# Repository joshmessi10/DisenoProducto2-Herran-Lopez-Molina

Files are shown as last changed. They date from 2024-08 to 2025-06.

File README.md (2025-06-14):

# 📦 Project Design: Smart Wallet

A multidisciplinary project focused on designing a Smart Wallet with enhanced security, tracking, and real-time data access, featuring custom PCB, mobile application, web integration, and mechanical design.

## 🧠 Features Overview
### 🔐 Security

- Unauthorized access protection
- Anti-loss alarm (Bluetooth disconnection)
- Fall detection
- Precise location recovery

### 📱 Functionality
- Bluetooth communication with Android app (BLE)

- Real-time statistics:
- Date and time of wallet openings
- Detection of abnormal movements
- Unauthorized access logs
- Last known location

### 🔧 Ergonomics and Durability

- Compact PCB design to fit in standard wallets
- BLE for low power consumption and long battery life

# 📁 Repository Structure
```plaintext
SmartWallet/
│
├── README.md                  <- General overview (this file)
│
├── hardware/
│   ├── README.md              <- Schematic, PCB layout (2D & 3D), test results
│   ├── schematic/             <- Altium files
│   ├── pcb/                   <- GERBER files, 2D/3D renders
│   └── testing/               <- Images/videos of pre-solder and post-solder testing
│
├── firmware/
│   ├── README.md              <- Microcontroller code overview
│   └── src/                   <- C/C++ source code
│
├── android_app/
│   ├── README.md              <- App features and Bluetooth integration
│   └── SmartWalletApp/        <- Full Android Studio project
│
├── web/
│   ├── README.md              <- Website functionality and usage
│   └── site/                  <- HTML/CSS/JS or framework files
│
├── database/
│   └── README.md              <- MongoDB Atlas structure and integration
│
└── casing_design/
    ├── README.md             
    └── 3d_models/             <- STL, OBJ, Fusion/Inventor files
```

## 🛠 Technologies Used

- **PCB Design:** Altium
- **Microcontroller:** nRF51822
- **Bluetooth:** BLE (Low Energy)
- **Mobile App:** Android (Java/Kotlin)
- **Database:** MongoDB Atlas
- **Web:** HTML/CSS/JS or framework (React/Vue/etc.)
- **3D Design:** Fusion 360

## 🚀 Getting Started

To explore each part of the project, navigate into the corresponding folder and refer to its README.md.

# 👥 Credits

Alejandro Buelvas García

Josh Sebastián López Murcia

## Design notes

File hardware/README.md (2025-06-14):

# PCB Design

Smart Wallet PCB Design using Altium Designer.

## Schematic

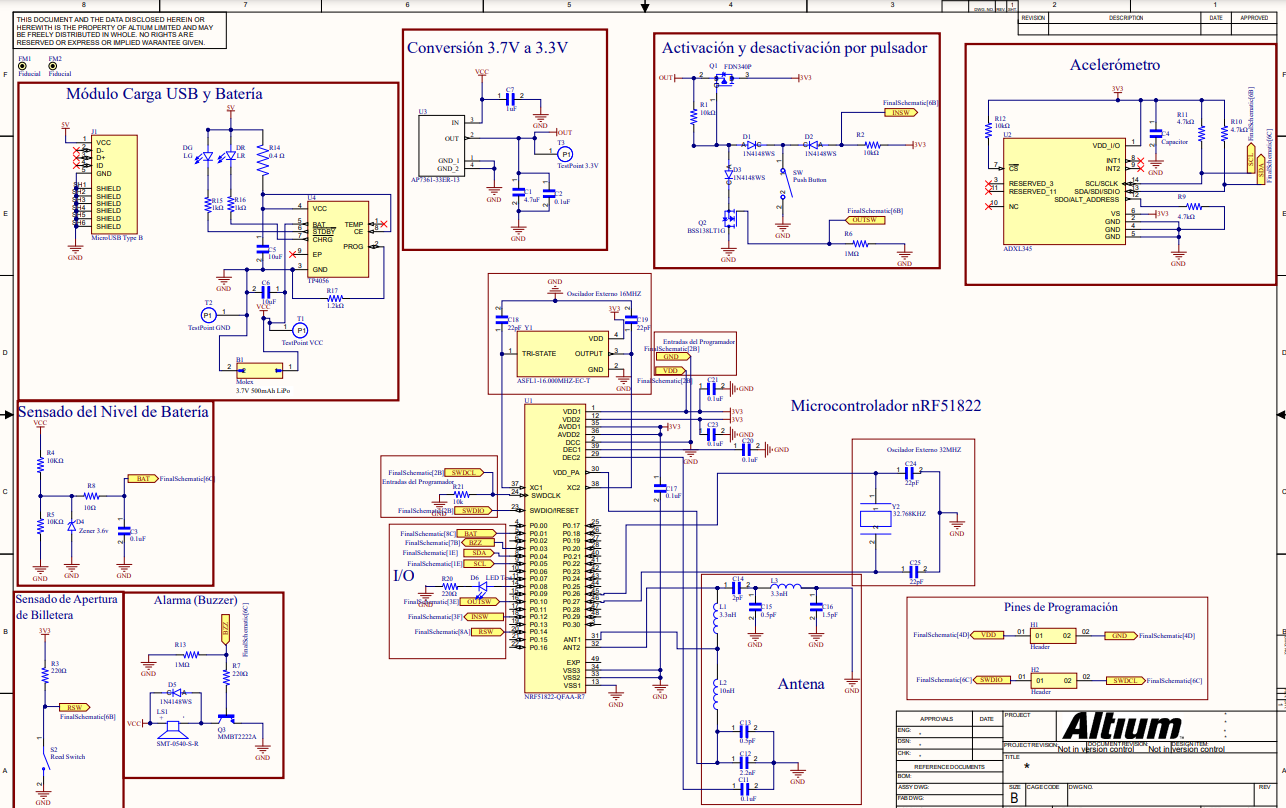
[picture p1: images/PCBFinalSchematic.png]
Schematic


## PCB Design Visualization

### 2D View

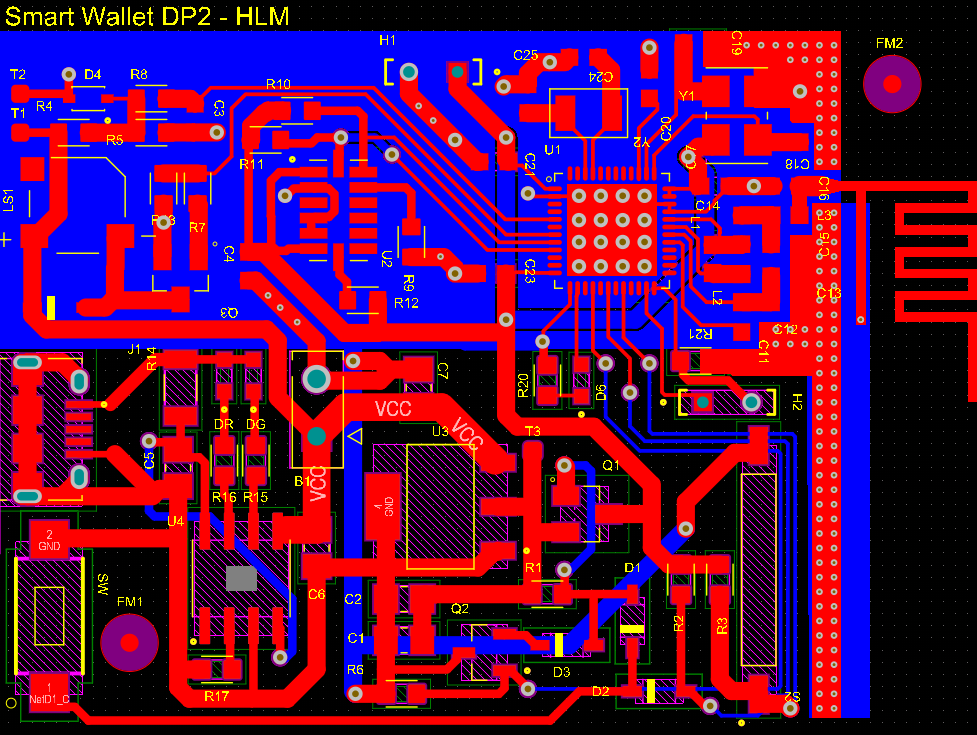
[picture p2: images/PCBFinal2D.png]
PCB 2D


### 3D View

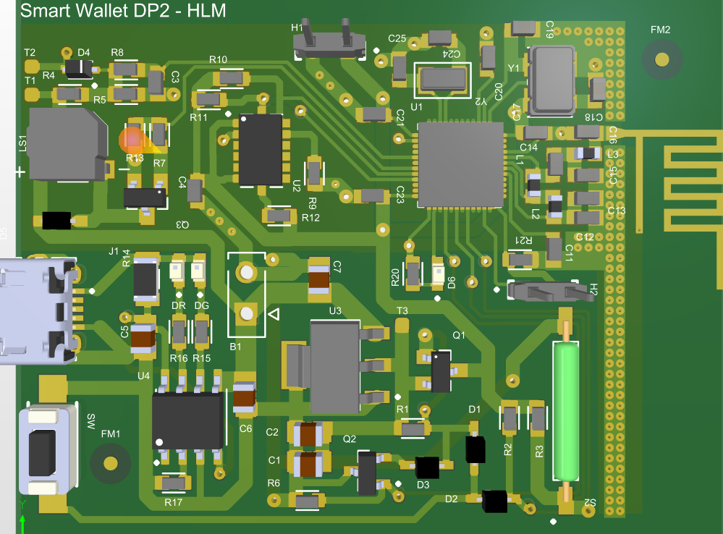
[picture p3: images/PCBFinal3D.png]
PCB 3D


[Download Link](https://drive.google.com/file/d/1_fBBA95fIbqjc8yl-Cb5X0gYM83vqySH/view?usp=sharing)

## PCB Assembly

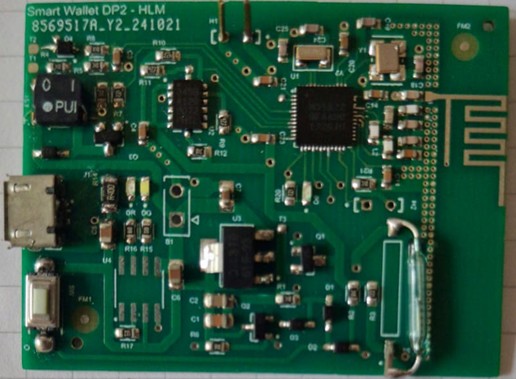
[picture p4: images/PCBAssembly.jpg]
PCB Assembly


Design Inspired from [Yunjia NRF51822](https://doc.riot-os.org/group__boards__yunjia-nrf51822.html#details)

[Integration of TP4056 Mini USB charge Module](https://www.electronicshub.org/tp4056-lithium-ion-battery-charger/)

2.4 GHz Monopole Antenna Design based on Antenna Design and RF Layout Guidelines by T Pattnayak

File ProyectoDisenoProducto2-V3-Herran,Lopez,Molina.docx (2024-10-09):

Proyecto Diseño de Producto 2

Estudiantes:

Juan Sebastián Herrán

Josh López

Sergio Molina

Asignatura:

Diseño de Producto 2

Universidad Sergio Arboleda

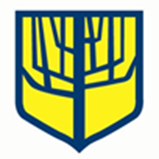
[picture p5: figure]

Escuela de Ciencias Exactas e Ingeniería

Ingeniería Electrónica

2024

Fase 1: Lluvia de Ideas

Producto | Ingeniería de Producto | | | Análisis de Mercado | | Restricciones
| ¿Se puede desarrollar? ¿Cómo? | ¿Es viable desarrollarlo? | | ¿A quién le interesa? | ¿Por qué sería llamativo? ¿Es una necesidad, una oportunidad o una solución? | A) Conectividad a la nube B) Batería C) Activación sin contactos mecánicos
| | Beneficios | Desventajas
Billetera Inteligente Ingeniería de Producto Análisis de Mercado Cumple Restricciones | Sí: Bloqueo RFID Conexión Wi-Fi /BLE GPS Alarma de Distancia Acelerómetro | Seguridad: Protección contra pérdidas y robos. Funcionalidad: Integración con otras tecnologías y dispositivos. Comodidad: Organización y pagos sin contacto | Complejidad (Integración de diferentes componentes en espacio reducido) Costos Bajo consumo de batería | Viajeros Frecuentes Estudiantes Profesionales Early Adopters | Es llamativo por las mejoras en seguridad y las nuevas funcionalidades que puede ofrecer. En Colombia casi no hay productos en el mercado. Representa una solución frente a robos en pro de la protección de los datos personales. | A) Sí B) Sí C) Sí
Chip Detector para ropa Ingeniería de Producto Análisis de Mercado Cumple Restricciones | Sí: Tecnología RFID (Chips y Lector) Conectividad Wi-Fi Pantalla Base de Datos | Inventario Preciso y Gestión eficiente Rastreo del Uso de cada Prenda Ahorro de Tiempo de selección de atuendos Recomendaciones personalizadas | Miniaturización y durabilidad de los chips Adaptación en la Ropa y Diseño a prueba de daños Software de Gestión para almacenamiento de datos en la nube y escalabilidad | Personas que buscan optimizar el uso de ropa, recibir sugerencias y reducir el tiempo de selección de ropa Personas que quieren ahorrar tiempo y esfuerzo comprando ropa Tiendas y fabricantes de ropa | Es llamativo porque brinda eficiencia, personalización e innovación implementando pequeños chips en la ropa. En varias tiendas de ropa de Colombia se utiliza esta tecnología. Representa una solución para la gestión del inventario y el tiempo que demora seleccionar un atuendo cada día. | A) Sí B) Sí C) Sí
Sistema de seguridad para maletas Ingeniería de Producto Análisis de Mercado Cumple Restricciones | No: Sensores magnéticos/Contacto Bocina Tecnología Bluetooth/Wifi | Seguridad contra robos y pérdidas Monitoreo de la maleta | Duración y Consumo Batería Colocación y Activación del Sistema Complejidad para el diseño e implementación del Sistema a prueba de cualquier tipo de robo Ej. Rotura de la maleta | Personas que buscan proteger sus pertenencias y/o llevan objetos valiosos | No es llamativo frente a un candado. Existen múltiples alternativas en el mercado. Representa una solución para los continuos robos de las pertenencias dentro de las maletas | A) Sí B) Sí C) Sí
Sistema de alarma para cocinas Ingeniería de Producto Análisis de Mercado Cumple Restricciones | Sí: Sensores de Gas/Humo/ Calor Mecanismo de cerrado de válvula Alarma sonora/visual Notificación Remota: Conectividad Wi-Fi | Mayor seguridad Tranquilidad frente a la no atención de la cocina o a encontrarse fuera del hogar Automatización del cierre de la válvula de gas Integración con otras tecnologías Detección temprana de fugas de gas y/o incendios Visualización de datos | Duración y Consumo Batería Sensado Preciso y Falsas Alarmas Mantenimiento Ubicación y Activación del Sistema Costo | Personas ocupadas/olvidadizas Personas que buscan proteger su hogar de fugas de gas y/o incendios | Es llamativo al presentar una solución, planteada como de bajo costo, que permite detectar con antelación y actuar de manera automática. Representa una solución para las fugas de gas y/o incendios, así como para el cierre automático de la válvula de gas. | A) Sí B) En Duda C) Sí
Sistema detector de consumo (ropa, comida) - . Ingeniería de Producto Análisis de Mercado No Cumple Restricciones | Sí: Conectividad a Internet Cámaras de alta resolución Visión Artificial | Control de inventario de ropa, personalizaciones etc. Control del inventario de comida, evita la perdida de algún producto y reduce los gastos del usuario en algunos casos Control del inventario de comida, control de salud y control de gastos en comida | Complejidad: Requiere mucho tiempo de desarrollo. Requiere diseñar y probar un sistema avanzado de detección, a prueba de fallas, en muy poco tiempo. Altos Costos | Personas que tengan bastante ropa/comida Personas que sean descuidadas o desorganizadas, empresas con un alto nivel de inventario Personas que quieran o requieran un control más sano del consumo de la comida actual | Es llamativo al presentar una utilidad para el control del inventario, sin importar cuál sea. Representa una oportunidad para controlar el uso de la ropa, el consumo de comida, el control de gastos, etc. | A) Sí B) No C) Sí
Sistema detector de disponibilidad de restaurantes Ingeniería de Producto Análisis de Mercado Cumple Restricciones | Sí: Conectividad Wi-Fi GPS (Datos de Ubicación) Aplicación Móvil Base de Datos | Menor tiempo de búsqueda de restaurantes disponibles Mayor Ingreso a Restaurantes | Simplicidad Beneficios principalmente brindados desde la nube Detección de presencia (mesa disponible/no disponible) | Personas que quieren localizar restaurantes libres en menor tiempo Restaurantes que quieren atraer clientes de manera efectiva | Es llamativo al presentar una solución innovadora y de bajo costo que se puede implementar en cualquier mesa y en cualquier restaurante, para atraer más clientela. Representa una solución para localizar los restaurantes con disponibilidad de manera rápida y efectiva. | A) Sí B) Sí C) En Duda
Espejo inteligente - . Ingeniería de Producto Análisis de Mercado No Cumple Restricciones | No: Pantalla Sensores Cámara: Vision Artificial IoT | Sencillez Estética Ahorro de Tiempo para arreglarse | Alta Complejidad Altos Costos por unidad Alto Precio | Todas las personas | Es llamativo al presentar una herramienta tecnológica para mejorar el estilo y la estética de las personas. Representa una oportunidad para ahorrarse tiempo arreglándose y recibir los mejores consejos. | A) Sí B) No C) Sí
Módulo GPS portable - . Ingeniería de Producto Análisis de Mercado No Cumple Restricciones | No: GPS Conectividad Wi-Fi | Seguridad Tranquilidad, Movilización Monitoreo de la Ubicación | Costo de producción vs. Precio Atractivo Muy Pocas funcionalidades Simplicidad Complejidad en la Conexión a Internet y a la nube Bajo consumo de batería | Niños | Es llamativo al presentar una herramienta tecnológica, planteada de bajo costo, para el monitoreo de la ubicación. Representa la atención a la necesidad del monitoreo constante de la ubicación de los niños. | A) Sí B) Sí C) No
Alacena Inteligente - . Ingeniería de Producto Análisis de Mercado No Cumple Restricciones | No: Sensores de Peso Actuadores para ubicar objetos Revisión de alimentos faltantes o cerca de vencerse | Reducción del desperdicio de alimentos Mejora de la organización Alimentación saludable Ahorro de tiempo | Complejidad Altos Costos vs. Proceso Manual Tamaño Tiempo de Desarrollo, Iteraciones y Pruebas Potencia Necesaria desde Alimentación del Sistema Requiere espacios fijos para los alimentos | Personas que quieren ahorrar tiempo en la cocina, y con gran capacidad adquisitiva. | Es llamativo al presentar una herramienta tecnológica para la organización automática de la alacena. Su alto precio no sería llamativo. Representa una oportunidad para ahorrarse tiempo en el proceso. | A) Sí B) No C) No
Estuche Gafas Inteligente - . Ingeniería de Producto Análisis de Mercado Cumple Restricciones | Sí: Tecnología Bluetooth Pantalla | Comodidad: Carga inalámbrica y sencilla. Funcionalidades Adicionales a un estuche convencional Integración: Se integra con otras tecnologías, como asistentes virtuales. | Pocas Funcionalidades Limitada Recolección de Estadísticas Complejidad para funcionalidades específicas | Personas que portan gafas que quieren un producto innovador Early-adopters | Es llamativo al presentar una innovación frente al estuche convencional. Representa una oportunidad para integrar la tecnología al estuche de gafas y conectarlo al IoT. | A) Sí B) Sí C) Sí

Análisis Criterios Iniciales:

DP2-T0-Herran,Lopez,Molina.xlsx (https://universidadsergioarboleda-my.sharepoint.com/:x:/g/personal/josh_lopez01_usa_edu_co/EcgmHX4n6xtBkdCwMJmsrzgBQwG7WUzlyEpB4xwgIX4yPQ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)

Fase 2: Filtrado de Ideas

Producto | ¿Es amplio el mercado objetivo? | ¿El mercado objetivo realmente se beneficiará del producto? | ¿Es técnicamente viable fabricar este producto? | ¿Generaría beneficios este producto en el tiempo?
Billetera Inteligente | Por supuesto. Todos los estudiantes y profesionales manejan una billetera para cuidar su dinero y documentos. | Por supuesto. El producto les garantizaría mayor seguridad en cuanto a la posibilidad de extraviar o ser víctimas de robo de su billetera. | Por supuesto. Se necesitarían componentes de bajo consumo y tamaño reducido. | Entre más popular se vuelva el producto, se generará una mayor rentabilidad, planteando un bajo costo y múltiples funcionalidades novedosas.
Chip Detector para ropa | No lo suficiente, pues solo las personas interesadas en la innovación del producto estarían dispuestas a comprarlo. Además, muchas tiendas de ropa ya implementan esta tecnología. | Por supuesto. A los usuarios les permitiría conocer la frecuencia de uso de su ropa y reducir tiempo al obtener recomendaciones de combinaciones de prendas para utilizar cada día. A las tiendas les permitiría un óptimo manejo del stock. | Por supuesto. Implica un menor costo en términos de tecnología RFID, pero todas las funcionalidades vendrían ligadas al software. | Depende de lo popular que se vuelva y lo útil que pueda llegar hacer, por lo que, al no poder producirse en masa, no generaría mucha rentabilidad.
Sistema de alarma para cocinas | Por supuesto. Todos los hogares podrían adquirir e implementar un sistema de bajo costo para sus cocinas. | Por supuesto. Desde el cerrado automático de la válvula de gas hasta el sistema de alarma y el monitoreo de datos, el producto presenta múltiples beneficios. | Por supuesto. Sin embargo, necesitaría una serie de pruebas para determinar los mejores sensores de bajo costo, y reducir el tamaño mientras siga cumpliendo sus requerimientos funcionales. | Depende tanto de su popularidad como principalmente de su precio, por lo que puede no generar mucha rentabilidad.
Sistema detector de nivel de llenado de restaurantes | Por supuesto. Todos los restaurantes pueden implementar el sensor que permite detectar si la mesa está ocupada, y conectar los datos a una aplicación móvil. Además, muchos empleados que buscan restaurante con disponibilidad para almorzar se verían beneficiados con la aplicación. | Por supuesto. En términos de eficiencia para encontrar restaurante disponible, y los propios restaurantes para obtener mayor clientela. | Por supuesto. No obstante, la mayor dificultad radica en detectar con certeza si una mesa se encuentra ocupada (sensor de presencia). | Depende de la cantidad de restaurantes que implementen dicha tecnología, por lo que en tanto se vuelva popular, puede generar rentabilidad. Sin embargo, no muchos restaurantes tenderían a apostar por el producto, pues el mayor beneficio recae en el cliente.

Ideas Seleccionadas:

1. Billetera Inteligente
2. Sistema de Alarma para cocinas

Fase 3: Desarrollo del concepto y prueba

3.1. Encuestas

1. Sistema de alarma para cocinas

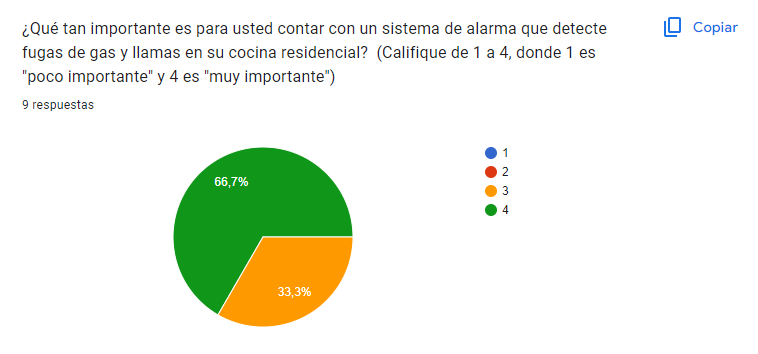
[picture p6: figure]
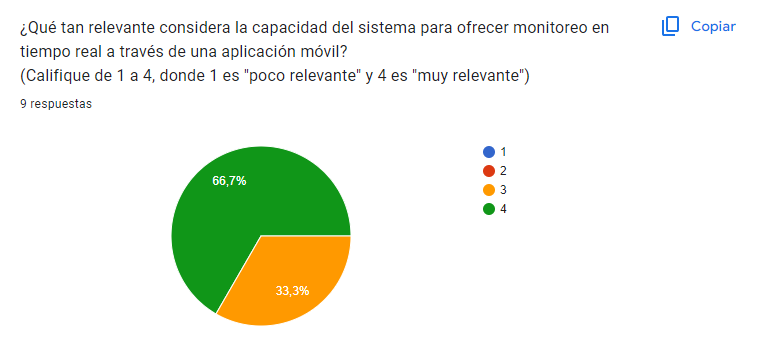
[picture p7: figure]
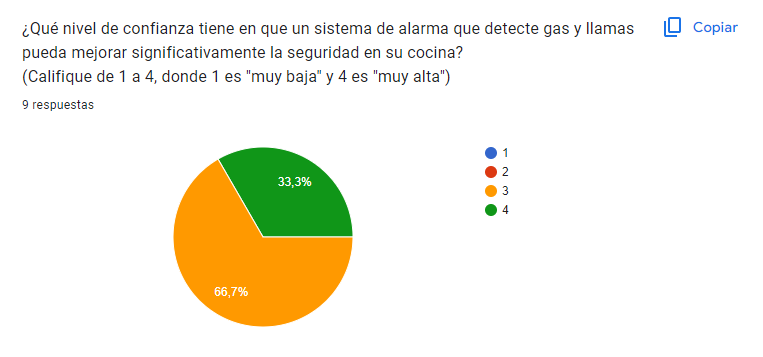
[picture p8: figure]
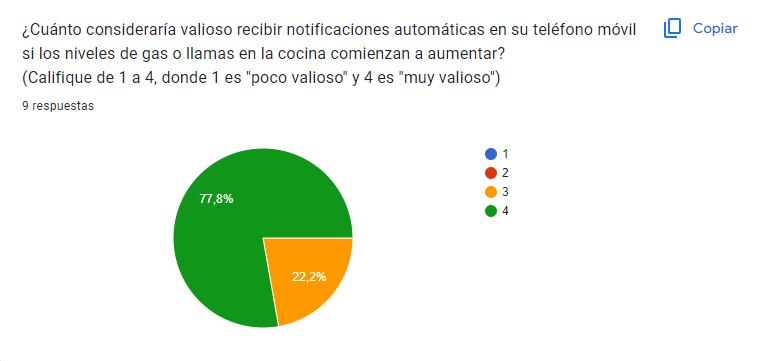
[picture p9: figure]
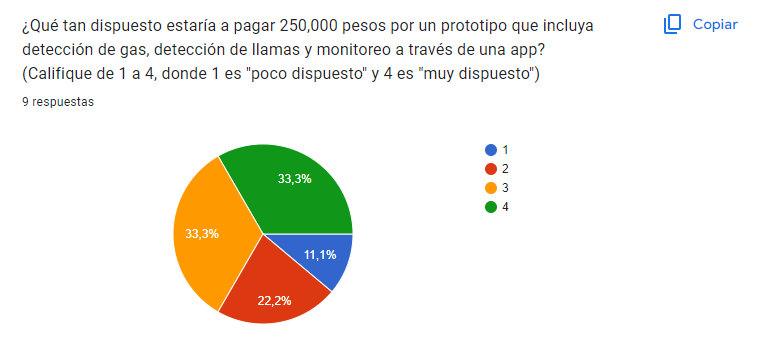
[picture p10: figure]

Link de la encuesta: https://forms.gle/PwD4ogpmBEbutgUVA

2. Billetera inteligente

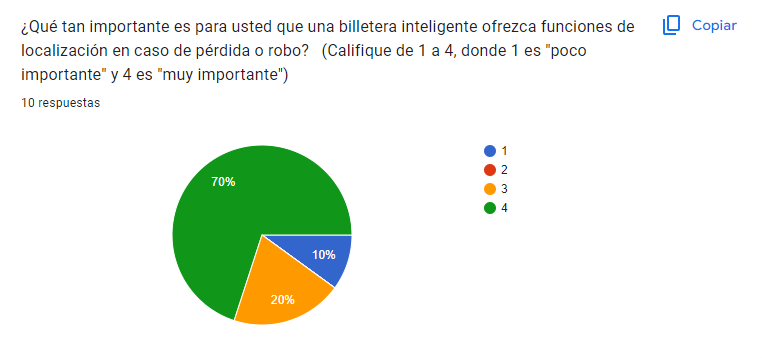
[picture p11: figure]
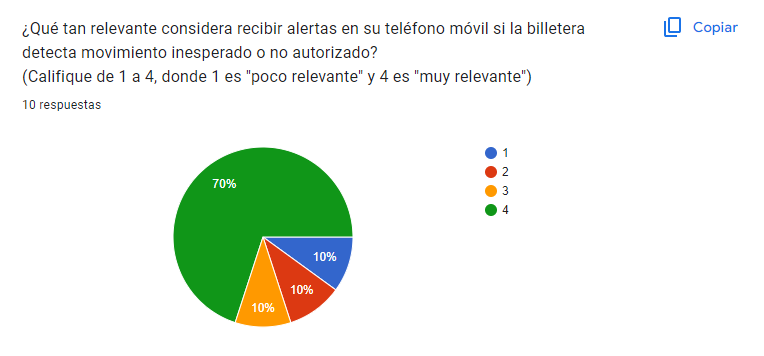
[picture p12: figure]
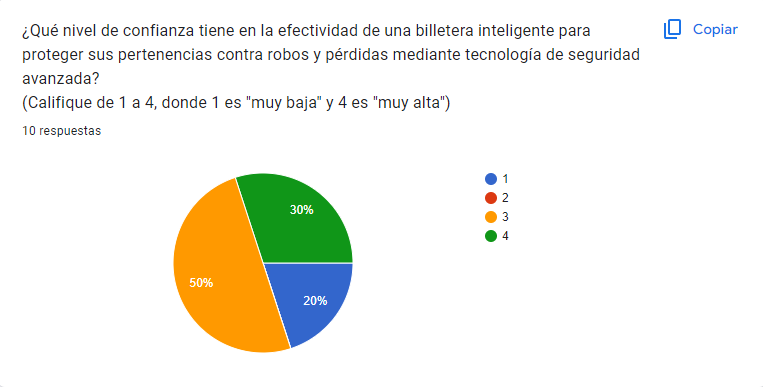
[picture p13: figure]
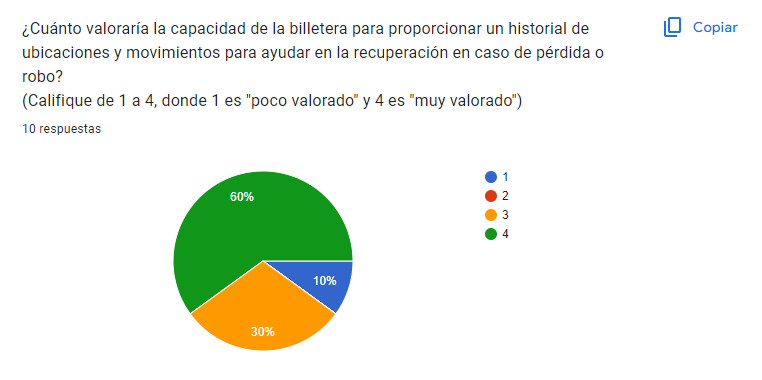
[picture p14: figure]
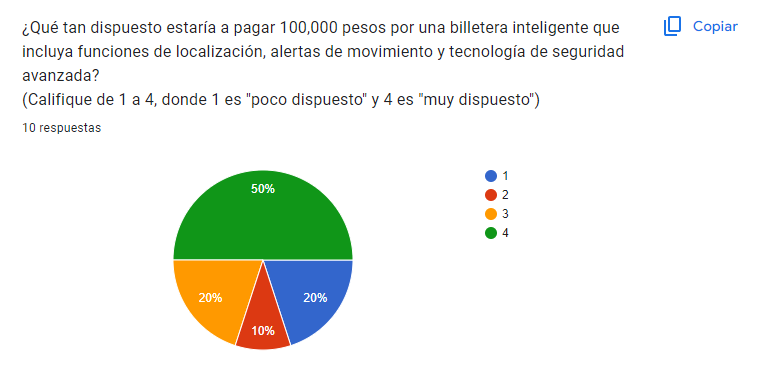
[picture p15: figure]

Link de la encuesta: https://forms.gle/VZ8JmRUWkLo8zy4EA

Fase 3: Desarrollo del concepto y prueba

A) Billetera Inteligente

1. Detalles de Marketing e Ingeniería

Marketing:

Identificación del Público Objetivo:

Jóvenes adultos y profesionales: Buscan tecnología innovadora, practicidad y seguridad.

Viajeros frecuentes: Valorarán las funciones de rastreo y seguridad en sus desplazamientos.

Aficionados a la tecnología: Adoptan rápidamente nuevos gadgets y buscan productos con características avanzadas.

Estrategia de Comunicación:

Redes sociales: Crear contenido atractivo y visualmente impactante para plataformas como Instagram, TikTok y Facebook.

Influencer marketing: Colaborar con influencers tecnológicos y de estilo de vida para llegar a un público más amplio.

Publicidad: Tiendas de tecnología y convenios con marcas de billeteras.

Canales de Venta:

Tiendas online: Vender a través de la propia tienda online y Marketplaces como Amazon, Mercado Libre, etc.

Tiendas físicas: Colaborar con tiendas de electrónica y accesorios de moda.

Distribuidores especializados: Llegar a un público más nicho a través de tiendas especializadas en tecnología.

Mensajes Clave:

Seguridad: Protección frente a robos y pérdidas.

Innovación: Tecnología de vanguardia y funcionalidades novedosas.

Conveniencia: Pagos sin contacto, organización de tarjetas y acceso a información importante.

Estilo: Diseño elegante y moderno que complementa cualquier atuendo.

1. Mercado Objetivo
- Jóvenes adultos y profesionales: Buscan tecnología innovadora, practicidad y seguridad.
- Viajeros frecuentes: Valorarán las funciones de rastreo y seguridad en sus desplazamientos.
- Aficionados a la tecnología: Adoptan rápidamente nuevos gadgets y buscan productos con características avanzadas.
2. Beneficios
- Seguridad:
  - Protección contra acceso no autorizado
  - Alarma por Alejamiento
  - Detección de caídas accidentales
  - Localización precisa en caso de pérdida
- Funcionalidad:
  - Integración con aplicación móvil
  - Comunicación via Bluetooth
  - Estadísticas en tiempo real: (Fecha y hora de apertura, movimientos anormales, registro de acceso no autorizado, registro de ubicación/última ubicación disponible)
- Ergonomía:
  - Tamaño reducido para integración en cualquier billetera
- Durabilidad:
  - BLE (Bluetooth Low Energy): Larga duración de la batería

Fase 3: Desarrollo del concepto y prueba

3.2. Requerimientos

A) Billetera Inteligente

Requerimientos Funcionales

3. Detección de apertura para protección con Intrusiones (Determinar si el acceso es o no autorizado) (Estados On/Off)
4. Notificación de Alejamiento de la billetera (Desconexión por Distancia mayor a 10 metros)
5. Autonomía Energética – 12 horas de batería
6. Detección de caída (-1g=-9.81m/s²)
7. Comunicación vía Bluetooth Low Energy (Protocolo BLE – 2.4GHz)
8. Almacenamiento de datos históricos (500 kilobytes)
9. Registro de actividades (apertura, movimientos sospechosos o no sospechosos) (12 horas de registro)
10. Visualización de datos históricos en tiempo real (1 min de retraso)
11. Alerta sonora (Estados On/Off)
12. Señalización visual apertura o cierre – Leds (Estados On/Off)
13. Activación desde aplicación móvil (Estados On/Off)
14. Notificación del estado de batería – Leds (Rojo-Verde)
15. Registro de movimientos bruscos (Intervalo entre ±2g y ±4g =±19.62g - ±39.24 g)
16. Función de autoapagado para ahorro de energía (1 min sin conexión al celular)
17. Botón de encendido/apagado (Estados On/Off)
18. Botón de desbloqueo manual (Estados On/Off)
19. Temporizador de apertura de la billetera (1 min)
20. Señal sonora para localizar tu billetera (Estados On/Off)
21. Señalización batería cargada – Leds (Estados On/Off)

Requerimientos No Funcionales

1. Tamaño Reducido (6x3x0.16cm) (En Revisión)
2. Latencia de comunicación aceptable (10 ms – Protocolo BLE)
3. Bajo consumo de energía (Ej. 0.3 W en alto consumo) (En revisión)
4. Costo asequible ($60000) (En Revisión)
5. Seguridad de la información – Restricción contra intrusiones (Protocolo X)

(Conexión con cifrado BLE)

(Protocolo TLS/SSL para la aplicación móvil)

6. Copias de seguridad automáticas

(Disponibles en la aplicación para las últimas 48 horas)

7. Durabilidad y resistencia

(Materiales por definir)

8. Interfaz de usuario intuitiva

Paso 1: Registro en la aplicación móvil

Paso 2: Conexión de la billetera inteligente

Paso 3: Visualización de datos

9. Peso reducido (Por Definir)

3.3. Diagrama de Bloques Nivel 1

Billetera Inteligente

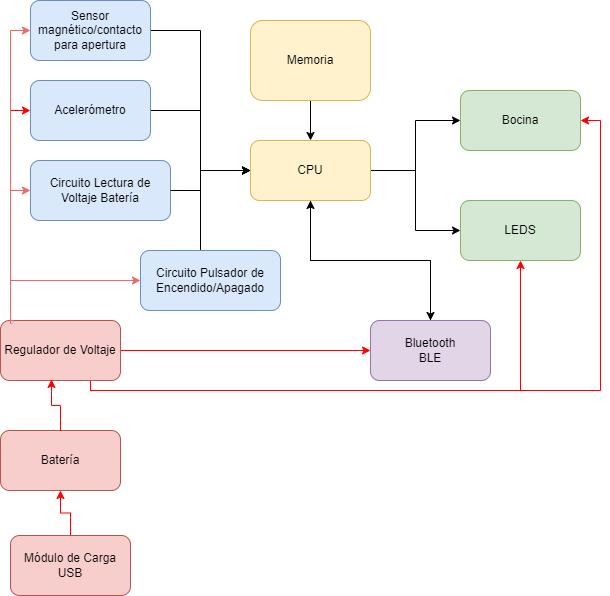
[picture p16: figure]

3.3.1. Búsqueda de Posibles Componentes

Microcontroladores

Componente | Precio | Voltaje | Corriente | Ventajas | Desventajas
ESP32 WROOM 32 | 20000-40000 COP | 2.7V-3.6V | Corriente típica de operación: 80mA | Integración de Wi-Fi y Bluetooth en un solo chip. Amplio soporte de GPIOs y periféricos. Muy popular y ampliamente soportado por la comunidad. | Mayor consumo de energía comparado con otros microcontroladores sin Wi-Fi/Bluetooth. Tamaño relativamente grande para aplicaciones ultracompactas.
Nordic nRF52840 QAAF | $10 USD | 1.7V-5.5V | Corriente típica de operación: Bluetooth 3.83-16.40 mA CPU: 2.8 – 5.2 mA | Muy bajo consumo de energía, ideal para aplicaciones alimentadas por batería. Excelente rendimiento en comunicaciones Bluetooth Low Energy (BLE). Alta integración de periféricos, incluyendo soporte para USB. | Menos potente en procesamiento que el ESP32. Más difícil de conseguir.
ESP32-S3 | 20000-40000 COP | 3-3.6V | 80-240mA | Mayor potencia de procesamiento, memoria y conectividad. | Mayor consumo de energía.
Nordic nRF51822 | $10 USD | 3.3V-5V | Corriente típica de operación: Bluetooth: 1.6mA-13mA Internal Radio Current Consumption: 7.8uA | Muy bajo consumo de energía, ideal para aplicaciones alimentadas por batería. Excelente rendimiento en comunicaciones Bluetooth Low Energy (BLE). | Menos potente en procesamiento que el ESP32. Difícil de conseguir. Menor cantidad de pines GPIO que en nRF52840.

ESP32 WROOM 32 : https://www.mouser.com/datasheet/2/891/esp-wroom-32_datasheet_en-1223836.pdf

Nordic nRF52840-DONGLE: https://infocenter.nordicsemi.com/pdf/nRF52840_PS_v1.1.pdf

ESP32-S3 : https://www.espressif.com/sites/default/files/documentation/esp32-s3_datasheet_en.pdf

Nordic nRF51822-DONGLE: nRF51x22 PS.book (nordicsemi.com) (https://infocenter.nordicsemi.com/pdf/nRF51822_PS_v3.1.pdf)

Acelerómetro

Componente | Precio | Voltaje | Corriente | Ventajas | Desventajas
MPU-6050 | 10000-15000 COP | 2.375V-3.46V | Corriente Operacional del: Acelerómetro: 500uA Giroscopio: 3.6mA | Integra acelerómetro y giroscopio, lo que permite la detección de movimiento en 6 ejes. Compatible con I2C, lo que facilita la integración con otros microcontroladores. Amplia comunidad de soporte y ejemplos de código disponibles. | Consumo de energía relativamente alto para aplicaciones alimentadas por batería. Sin características de bajo ruido o alta precisión en comparación con otros sensores.
ADXL345 | 7000-12000 COP | 2V-3.6V | 30uA – 150 uA (2.5V) | Bajo consumo de energía, ideal para aplicaciones alimentadas por batería. Amplio rango de ±2g, ±4g, ±8g, ±16g, configurable según la aplicación. Comunicación por I2C y SPI, facilitando la integración. | No es el más preciso en comparación con otros acelerómetros más avanzados. Tecnología más antigua, aunque sigue siendo ampliamente utilizada.

MPU6050 : https://www.alldatasheet.es/datasheet-pdf/download/517744/ETC1/MPU-6050.html

ADXL345: https://www.analog.com/media/en/technical-documentation/data-sheets/adxl345.pdf

LEDs

* Dependiendo del microcontrolador, la tarjeta puede tener LED, por lo que al elegir la tarjeta Nordic, no se incluye.

Componente | Precio | Voltaje | Corriente | Ventajas | Desventajas
Leds SMD 0805 | 300 COP | 2.7v-3.7v | 25 mA | Tamaño compacto, ideal para aplicaciones donde el espacio es limitado. Disponible en una variedad de colores. Bajo costo y ampliamente disponible. | Brillo limitado en comparación con LEDs más grandes. Requiere una cuidadosa soldadura debido a su pequeño tamaño.
Leds SMD 5050 | 400 COP | 2V-3.6V | 60-75 mA | Alto brillo, adecuado para iluminación y efectos visuales. Capaz de emitir varios colores (RGB) en un solo paquete. Relativamente fácil de soldar debido a su tamaño. | Consumo de energía más alto debido a los múltiples chips. Ocupa más espacio en la PCB.
Leds SMD 3528 | 300 COP | 1.7V-2.4V | 50 mA | Tamaño intermedio, adecuado para aplicaciones de señalización y decoración. Disponible en varios colores, incluyendo opciones de alto brillo. Más eficiente que los LEDs 5050 en términos de consumo de energía por chip | Menos brillante que los LEDs 5050. Menor gama de colores comparado con LEDs RGB.

Led SMD 0805: https://www.mouser.com/datasheet/2/143/17-21-BHC-AP1Q2-3T_datasheet-51933.pdf

Led SMD 5050: https://www.iled.com/class/INNOVAEditor/assets/YeniDatasheets/4050-4055-4057.pdf

Led SMD 3528: https://www.sigmaelectronica.net/wp-content/uploads/2018/08/LED-3528BLANCO.pdf

Alimentación

Componente | Precio | Voltaje | Corriente | Ventajas | Desventajas
Batería de litio-polímero (LiPo) | 25000-30000 COP | 3.7v | 500 mAh | Alta densidad de energía, lo que permite una mayor capacidad en un tamaño pequeño. Forma flexible, disponible en diferentes formas y tamaños, ideal para aplicaciones compactas. Peso ligero, adecuado para dispositivos portátiles. | Requiere un manejo cuidadoso para evitar sobrecargas o sobre-descargas, que pueden causar daños. Vida útil limitada en comparación con otras baterías recargables. Puede ser más cara que otras opciones de baterías.

Batería Li-Po: https://www.zamux.co/bateria-recargable-litio-37v-500ma

Módulo de Carga

Componente | Precio | Voltaje | Corriente | Ventajas | Desventajas
TP4056 y puerto Mini USB 1050170002 | 4000 COP | Input supply voltage: 4.25 – 6.5V | Input supply current: 35uA – 2 mA | Muy económico y ampliamente disponible. Configurable para diferentes corrientes de carga mediante la modificación de una resistencia. Fácil de integrar en proyectos DIY debido a su tamaño compacto. | Sin protección integrada por defecto (aunque hay versiones con protección). La corriente de carga puede ser limitada para baterías de mayor capacidad. Requiere soldadura si se necesita ajustar la corriente de carga.
Módulo de carga MCP73831 | 18000 COP | Input supply voltage: 3.75 – 6V | Input supply current: 510uA – 1.5 mA | Bajo consumo en reposo, ideal para aplicaciones de bajo consumo de energía. Muy eficiente en la gestión de la carga, prolongando la vida útil de la batería. Pequeño y fácil de integrar en PCB personalizadas. | Corriente de carga más baja (hasta 500 mA), lo que puede ser una limitación para baterías más grandes. Puede requerir componentes externos adicionales para ajustar el circuito.

TP4056: https://radioremont.com/wa-data/public/shop/products/32/33/3332/attachments/TP4056.pdf

MCP73831: https://www.alldatasheet.es/datasheet-pdf/download/305677/MICROCHIP/MCP73831.html

Circuito de Activación por Pulsador

Pulsador

Componente | Precio | Voltaje | Corriente | Ventajas | Desventajas
SW 4P NO | 400 COP | <42 V | <50mA | Tamaño pequeño, bajo costo. | Su tamaño puede dificultar la experiencia de usuario.

SW 4 Pines: https://cdn.soselectronic.com/productdata/f4/94/44a0b902/0862-8101.pdf

Mosfet Tipo N

Componente | Precio | Voltaje | Corriente | Ventajas | Desventajas
2N7002 | 600 COP | VGS (th): 1V to 2.5V | I DSS: 1 to 500 uA | Tamaño pequeño, bajo costo. | Difícil de soldar.

2N7002: https://www.diodes.com/assets/Datasheets/ds11303.pdf

Mosfet Tipo P

Componente | Precio | Voltaje | Corriente | Ventajas | Desventajas
FDN340P | 300 COP | VGS (th): -0.4V to -1.5V | I DSS: 1 to 10 uA | Tamaño pequeño, bajo costo. | Difícil de soldar

FDN340P: https://www.onsemi.com/pdf/datasheet/fdn340p-d.pdf

Resistencias:

Componente | Precio | Voltaje | Corriente
RES 1206 | 500 COP | Max 3.3V | Varía según el valor de la resistencia
RES 0603 | 500 COP | Max 3.3V | Varía según el valor de la resistencia
RES 0804 | 500 COP | Max 3.3V | Varía según el valor de la resistencia

Diodos

Componente | Precio | Voltaje | Corriente | Ventajas | Desventajas
1N4004 SMD | 200 COP | 0.7V | Average Forward Rectifier Current: 100mA | Tamaño pequeño, bajo consumo de energía, bajo costo

1N4007: https://www.alldatasheet.es/datasheet-pdf/download/209682/FCI/1N4007.html

Sensor de Apertura: Detección de Billetera Abierta/Cerrada

Componente | Precio | Voltaje | Corriente | Ventajas | Desventajas
Reed Switch ORD213 | 1200 COP | < 24 V | <100mA | Tamaño pequeño, bajo costo. | Requiere un imán/campo magnético al otro extremo para su activación/desactivación.

ORD213: https://standexelectronics.com/wp-content/uploads/OKI_Reed_Switch_ORD213.pdf

Regulador de Voltaje 3.3V

ME6217-3.3V | $0.075 USD | 3.4-6.5V Dropout Voltage: 100mV | Max Current Output: 800mA | Baja Caída de Voltaje Amplio rango de voltaje de operación | Reducción en la corriente de salida Difícil de conseguir
MIC502-3.3V | 600 COP | 3.4-6.5V Dropout Voltage: 150mV | Max Current Output : 500 mA Quiescent Current: 5uA | Fácil de conseguir Baja caída de voltaje Rango de Voltaje de Operación Óptimo | Voltaje de caída más alto dependiendo de la corriente de entrada Corriente de salida más baja
AP7361-33ER-13 | 1,547 COP | 2.2V – 6V. | 70 µA típica. | Capacidad de corriente de salida de hasta 1 amperio, es pequeño, adecuado para un montaje superficial. | Si se requiere de una potencia alta no es el regulador más adecuado, se consigue pero no es tan común solo pocas tiendas lo venden.

ME6217C33: MICRONE(Nanjing Micro One Elec) ME6217C33M5G Datasheet (lcsc.com) (https://www.lcsc.com/datasheet/lcsc_datasheet_1912111437_MICRONE-Nanjing-Micro-One-Elec-ME6217C33M5G_C427602.pdf)

MIC5205-3.3: https://www.vistronica.com/index.php?controller=attachment&id_attachment=574

Capacitores y Condensadores

Condensador Cerámico e Inductancia SMD | | 600 COP | | | Bajo costo Tamaño Reducido | Entre menor tamaño, más difícil para soldar

Diodo Zener

Zener SMD 3.6V | 200 COP | 3.6V | 5mA | Bajo costo Tamaño Reducido | Difícil para soldar

Zener 3.6V: Diodo Zener BZT52C3V6S W4 3.6V 200mW SMD SOD-323 (vistronica.com) (https://www.vistronica.com/componentes-activos/diodos/diodo-zener-bzt52c3v6s-w4-3-6v-200mw-smd-sod-323-detail.html)

Bocina

Bocina piezoeléctrica SMD: CMT-2020 | $2 USD | 2.5V-4.5V | 120mA | Tamaño pequeño, consumo de voltaje apropiado, bajo costo | No tiene un volumen muy alto, el sonido puede no ser de tan alta calidad Consumo de corriente considerable Difícil de conseguir
Bocina SMT-0540-S-R | 1250 COP | 3-12V | 30mA | Menor consumo de corriente Más fácil de conseguir | Tamaño más grande Volumen variable

SMT-0540-S-R: https://co.mouser.com/ProductDetail/PUI-Audio/SMT-0540-S-R?qs=e16JbV5WBEu5VaDVzQP23Q%3D%3D

3.4.2 Diagrama de Bloques Nivel 2

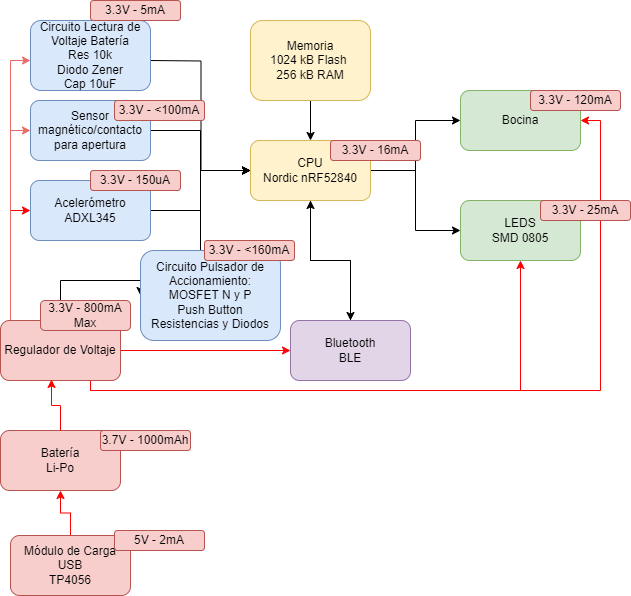
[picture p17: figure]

Fase 4: Diseño de Esquemático

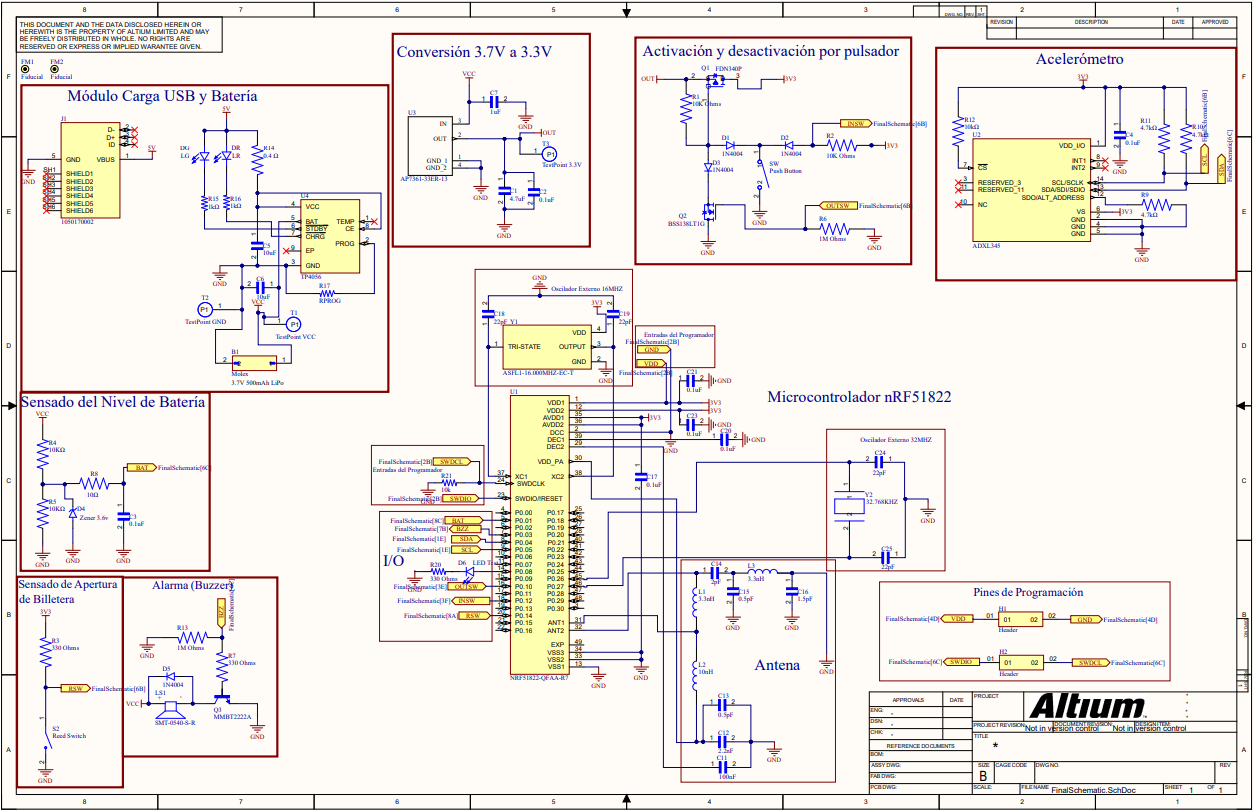
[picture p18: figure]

Fase 5: Diseño de PCB

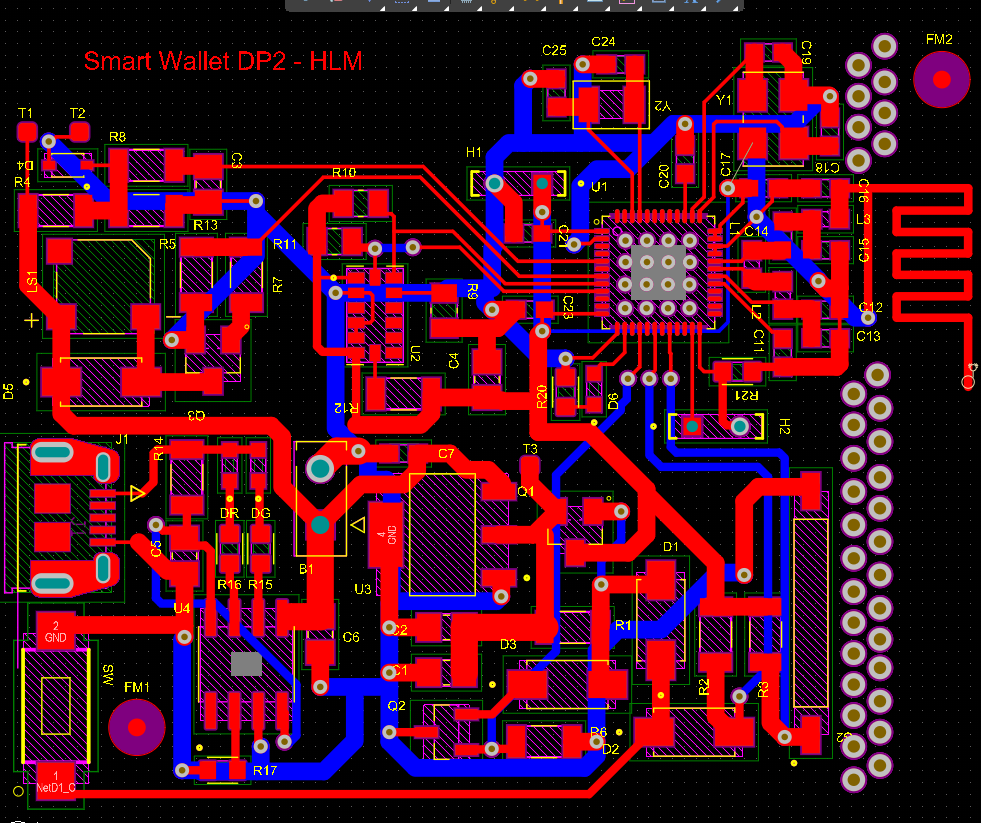
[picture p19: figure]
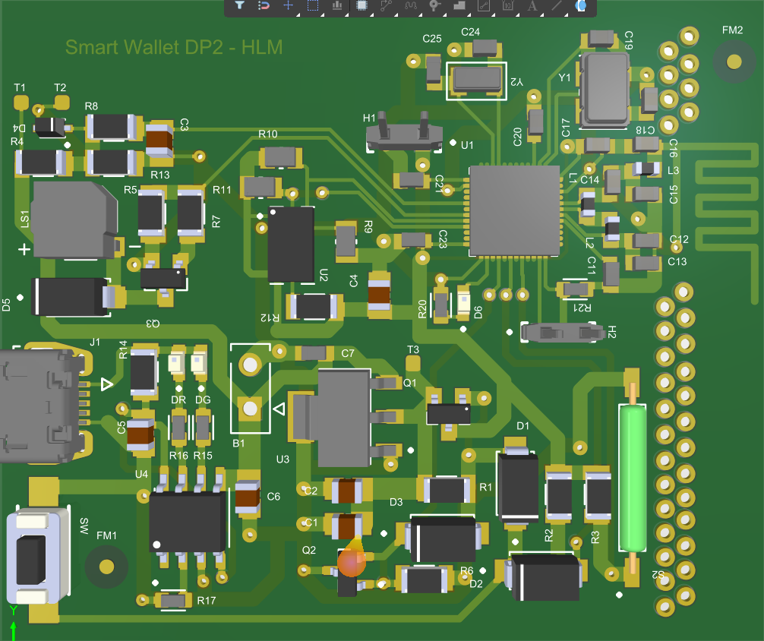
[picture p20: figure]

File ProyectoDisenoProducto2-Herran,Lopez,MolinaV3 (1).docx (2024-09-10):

Proyecto Diseño de Producto 2

Estudiantes:

Juan Sebastián Herrán

Josh López

Sergio Molina

Asignatura:

Diseño de Producto 2

Universidad Sergio Arboleda


Escuela de Ciencias Exactas e Ingeniería

Ingeniería Electrónica

2024

Fase 1: Lluvia de Ideas

Producto | Ingeniería de Producto | | | Análisis de Mercado | | Restricciones
| ¿Se puede desarrollar? ¿Cómo? | ¿Es viable desarrollarlo? | | ¿A quién le interesa? | ¿Por qué sería llamativo? ¿Es una necesidad, una oportunidad o una solución? | A) Conectividad a la nube B) Batería C) Activación sin contactos mecánicos
| | Beneficios | Desventajas
Billetera Inteligente Ingeniería de Producto Análisis de Mercado Cumple Restricciones | Sí: Bloqueo RFID Conexión Wi-Fi /BLE GPS Alarma de Distancia Acelerómetro | Seguridad: Protección contra pérdidas y robos. Funcionalidad: Integración con otras tecnologías y dispositivos. Comodidad: Organización y pagos sin contacto | Complejidad (Integración de diferentes componentes en espacio reducido) Costos Bajo consumo de batería | Viajeros Frecuentes Estudiantes Profesionales Early Adopters | Es llamativo por las mejoras en seguridad y las nuevas funcionalidades que puede ofrecer. En Colombia casi no hay productos en el mercado. Representa una solución frente a robos en pro de la protección de los datos personales. | A) Sí B) Sí C) Sí
Chip Detector para ropa Ingeniería de Producto Análisis de Mercado Cumple Restricciones | Sí: Tecnología RFID (Chips y Lector) Conectividad Wi-Fi Pantalla Base de Datos | Inventario Preciso y Gestión eficiente Rastreo del Uso de cada Prenda Ahorro de Tiempo de selección de atuendos Recomendaciones personalizadas | Miniaturización y durabilidad de los chips Adaptación en la Ropa y Diseño a prueba de daños Software de Gestión para almacenamiento de datos en la nube y escalabilidad | Personas que buscan optimizar el uso de ropa, recibir sugerencias y reducir el tiempo de selección de ropa Personas que quieren ahorrar tiempo y esfuerzo comprando ropa Tiendas y fabricantes de ropa | Es llamativo porque brinda eficiencia, personalización e innovación implementando pequeños chips en la ropa. En varias tiendas de ropa de Colombia se utiliza esta tecnología. Representa una solución para la gestión del inventario y el tiempo que demora seleccionar un atuendo cada día. | A) Sí B) Sí C) Sí
Sistema de seguridad para maletas Ingeniería de Producto Análisis de Mercado Cumple Restricciones | No: Sensores magnéticos/Contacto Bocina Tecnología Bluetooth/Wifi | Seguridad contra robos y pérdidas Monitoreo de la maleta | Duración y Consumo Batería Colocación y Activación del Sistema Complejidad para el diseño e implementación del Sistema a prueba de cualquier tipo de robo Ej. Rotura de la maleta | Personas que buscan proteger sus pertenencias y/o llevan objetos valiosos | No es llamativo frente a un candado. Existen múltiples alternativas en el mercado. Representa una solución para los continuos robos de las pertenencias dentro de las maletas | A) Sí B) Sí C) Sí
Sistema de alarma para cocinas Ingeniería de Producto Análisis de Mercado Cumple Restricciones | Sí: Sensores de Gas/Humo/ Calor Mecanismo de cerrado de válvula Alarma sonora/visual Notificación Remota: Conectividad Wi-Fi | Mayor seguridad Tranquilidad frente a la no atención de la cocina o a encontrarse fuera del hogar Automatización del cierre de la válvula de gas Integración con otras tecnologías Detección temprana de fugas de gas y/o incendios Visualización de datos | Duración y Consumo Batería Sensado Preciso y Falsas Alarmas Mantenimiento Ubicación y Activación del Sistema Costo | Personas ocupadas/olvidadizas Personas que buscan proteger su hogar de fugas de gas y/o incendios | Es llamativo al presentar una solución, planteada como de bajo costo, que permite detectar con antelación y actuar de manera automática. Representa una solución para las fugas de gas y/o incendios, así como para el cierre automático de la válvula de gas. | A) Sí B) En Duda C) Sí
Sistema detector de consumo (ropa, comida) - . Ingeniería de Producto Análisis de Mercado No Cumple Restricciones | Sí: Conectividad a Internet Cámaras de alta resolución Visión Artificial | Control de inventario de ropa, personalizaciones etc. Control del inventario de comida, evita la perdida de algún producto y reduce los gastos del usuario en algunos casos Control del inventario de comida, control de salud y control de gastos en comida | Complejidad: Requiere mucho tiempo de desarrollo. Requiere diseñar y probar un sistema avanzado de detección, a prueba de fallas, en muy poco tiempo. Altos Costos | Personas que tengan bastante ropa/comida Personas que sean descuidadas o desorganizadas, empresas con un alto nivel de inventario Personas que quieran o requieran un control más sano del consumo de la comida actual | Es llamativo al presentar una utilidad para el control del inventario, sin importar cuál sea. Representa una oportunidad para controlar el uso de la ropa, el consumo de comida, el control de gastos, etc. | A) Sí B) No C) Sí
Sistema detector de disponibilidad de restaurantes Ingeniería de Producto Análisis de Mercado Cumple Restricciones | Sí: Conectividad Wi-Fi GPS (Datos de Ubicación) Aplicación Móvil Base de Datos | Menor tiempo de búsqueda de restaurantes disponibles Mayor Ingreso a Restaurantes | Simplicidad Beneficios principalmente brindados desde la nube Detección de presencia (mesa disponible/no disponible) | Personas que quieren localizar restaurantes libres en menor tiempo Restaurantes que quieren atraer clientes de manera efectiva | Es llamativo al presentar una solución innovadora y de bajo costo que se puede implementar en cualquier mesa y en cualquier restaurante, para atraer más clientela. Representa una solución para localizar los restaurantes con disponibilidad de manera rápida y efectiva. | A) Sí B) Sí C) En Duda
Espejo inteligente - . Ingeniería de Producto Análisis de Mercado No Cumple Restricciones | No: Pantalla Sensores Cámara: Vision Artificial IoT | Sencillez Estética Ahorro de Tiempo para arreglarse | Alta Complejidad Altos Costos por unidad Alto Precio | Todas las personas | Es llamativo al presentar una herramienta tecnológica para mejorar el estilo y la estética de las personas. Representa una oportunidad para ahorrarse tiempo arreglándose y recibir los mejores consejos. | A) Sí B) No C) Sí
Módulo GPS portable - . Ingeniería de Producto Análisis de Mercado No Cumple Restricciones | No: GPS Conectividad Wi-Fi | Seguridad Tranquilidad, Movilización Monitoreo de la Ubicación | Costo de producción vs. Precio Atractivo Muy Pocas funcionalidades Simplicidad Complejidad en la Conexión a Internet y a la nube Bajo consumo de batería | Niños | Es llamativo al presentar una herramienta tecnológica, planteada de bajo costo, para el monitoreo de la ubicación. Representa la atención a la necesidad del monitoreo constante de la ubicación de los niños. | A) Sí B) Sí C) No
Alacena Inteligente - . Ingeniería de Producto Análisis de Mercado No Cumple Restricciones | No: Sensores de Peso Actuadores para ubicar objetos Revisión de alimentos faltantes o cerca de vencerse | Reducción del desperdicio de alimentos Mejora de la organización Alimentación saludable Ahorro de tiempo | Complejidad Altos Costos vs. Proceso Manual Tamaño Tiempo de Desarrollo, Iteraciones y Pruebas Potencia Necesaria desde Alimentación del Sistema Requiere espacios fijos para los alimentos | Personas que quieren ahorrar tiempo en la cocina, y con gran capacidad adquisitiva. | Es llamativo al presentar una herramienta tecnológica para la organización automática de la alacena. Su alto precio no sería llamativo. Representa una oportunidad para ahorrarse tiempo en el proceso. | A) Sí B) No C) No
Estuche Gafas Inteligente - . Ingeniería de Producto Análisis de Mercado Cumple Restricciones | Sí: Tecnología Bluetooth Pantalla | Comodidad: Carga inalámbrica y sencilla. Funcionalidades Adicionales a un estuche convencional Integración: Se integra con otras tecnologías, como asistentes virtuales. | Pocas Funcionalidades Limitada Recolección de Estadísticas Complejidad para funcionalidades específicas | Personas que portan gafas que quieren un producto innovador Early-adopters | Es llamativo al presentar una innovación frente al estuche convencional. Representa una oportunidad para integrar la tecnología al estuche de gafas y conectarlo al IoT. | A) Sí B) Sí C) Sí

Análisis Criterios Iniciales:

DP2-T0-Herran,Lopez,Molina.xlsx (https://universidadsergioarboleda-my.sharepoint.com/:x:/g/personal/josh_lopez01_usa_edu_co/EcgmHX4n6xtBkdCwMJmsrzgBQwG7WUzlyEpB4xwgIX4yPQ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)

Fase 2: Filtrado de Ideas

Producto | ¿Es amplio el mercado objetivo? | ¿El mercado objetivo realmente se beneficiará del producto? | ¿Es técnicamente viable fabricar este producto? | ¿Generaría beneficios este producto en el tiempo?
Billetera Inteligente | Por supuesto. Todos los estudiantes y profesionales manejan una billetera para cuidar su dinero y documentos. | Por supuesto. El producto les garantizaría mayor seguridad en cuanto a la posibilidad de extraviar o ser víctimas de robo de su billetera. | Por supuesto. Se necesitarían componentes de bajo consumo y tamaño reducido. | Entre más popular se vuelva el producto, se generará una mayor rentabilidad, planteando un bajo costo y múltiples funcionalidades novedosas.
Chip Detector para ropa | No lo suficiente, pues solo las personas interesadas en la innovación del producto estarían dispuestas a comprarlo. Además, muchas tiendas de ropa ya implementan esta tecnología. | Por supuesto. A los usuarios les permitiría conocer la frecuencia de uso de su ropa y reducir tiempo al obtener recomendaciones de combinaciones de prendas para utilizar cada día. A las tiendas les permitiría un óptimo manejo del stock. | Por supuesto. Implica un menor costo en términos de tecnología RFID, pero todas las funcionalidades vendrían ligadas al software. | Depende de lo popular que se vuelva y lo útil que pueda llegar hacer, por lo que, al no poder producirse en masa, no generaría mucha rentabilidad.
Sistema de alarma para cocinas | Por supuesto. Todos los hogares podrían adquirir e implementar un sistema de bajo costo para sus cocinas. | Por supuesto. Desde el cerrado automático de la válvula de gas hasta el sistema de alarma y el monitoreo de datos, el producto presenta múltiples beneficios. | Por supuesto. Sin embargo, necesitaría una serie de pruebas para determinar los mejores sensores de bajo costo, y reducir el tamaño mientras siga cumpliendo sus requerimientos funcionales. | Depende tanto de su popularidad como principalmente de su precio, por lo que puede no generar mucha rentabilidad.
Sistema detector de nivel de llenado de restaurantes | Por supuesto. Todos los restaurantes pueden implementar el sensor que permite detectar si la mesa está ocupada, y conectar los datos a una aplicación móvil. Además, muchos empleados que buscan restaurante con disponibilidad para almorzar se verían beneficiados con la aplicación. | Por supuesto. En términos de eficiencia para encontrar restaurante disponible, y los propios restaurantes para obtener mayor clientela. | Por supuesto. No obstante, la mayor dificultad radica en detectar con certeza si una mesa se encuentra ocupada (sensor de presencia). | Depende de la cantidad de restaurantes que implementen dicha tecnología, por lo que en tanto se vuelva popular, puede generar rentabilidad. Sin embargo, no muchos restaurantes tenderían a apostar por el producto, pues el mayor beneficio recae en el cliente.

Ideas Seleccionadas:

1. Billetera Inteligente
2. Sistema de Alarma para cocinas

Fase 3: Desarrollo del concepto y prueba

3.1. Encuestas

1. Sistema de alarma para cocinas


Link de la encuesta: https://forms.gle/PwD4ogpmBEbutgUVA

2. Billetera inteligente


Link de la encuesta: https://forms.gle/VZ8JmRUWkLo8zy4EA

Fase 3: Desarrollo del concepto y prueba

3.2. Requerimientos

A) Billetera Inteligente

Requerimientos Funcionales

1. Detección de apertura para protección con Intrusiones (Determinar si el acceso es o no autorizado) (Estados On/Off)
2. Notificación de Alejamiento de la billetera (Desconexión por Distancia mayor a 10 metros)
3. Autonomía Energética – 12 horas de batería
4. Detección de caída (-1g=-9.81m/s²)
5. Comunicación vía Bluetooth Low Energy (Protocolo BLE – 2.4GHz)
6. Almacenamiento de datos históricos ( Megabyte)(Definir según microcontrolador)
7. Registro de actividades (apertura, movimientos sospechosos o no sospechosos) (12 horas de registro)
8. Visualización de datos históricos en tiempo real (1 min de retraso)
9. Alerta sonora (Estados On/Off)
10. Señalización visual apertura o cierre – Leds (Estados On/Off)
11. Activación desde aplicación móvil (Estados On/Off)
12. Notificación del estado de batería – Leds (Rojo-Verde)
13. Registro de movimientos bruscos (Intervalo entre ±2g y ±4g =±19.62g - ±39.24 g)
14. Función de autoapagado para ahorro de energía (1 min sin conexión al celular)
15. Botón de encendido/apagado (Estados On/Off)
16. Botón de desbloqueo manual (Estados On/Off)
17. Temporizador de apertura de la billetera (1 min)
18. Señal sonora para localizar tu billetera (Estados On/Off)

Requerimientos No Funcionales

1. Tamaño Reducido (6x3x0.16cm) (En Revisión)
2. Latencia de comunicación aceptable (10 ms – Protocolo BLE)
3. Bajo consumo de energía (Ej. 0.3 W en alto consumo) (En revisión)
4. Costo asequible ($60000) (En Revisión)
5. Seguridad de la información – Restricción contra intrusiones (Protocolo X)

(Conexión con cifrado BLE)

(Protocolo TLS/SSL para la aplicación móvil)

6. Copias de seguridad automáticas

(Disponibles en la aplicación para las últimas 48 horas)

7. Durabilidad y resistencia

(Materiales por definir)

8. Interfaz de usuario intuitiva

Paso 1: Registro en la aplicación móvil

Paso 2: Conexión de la billetera inteligente

Paso 3: Visualización de datos

9. Peso reducido (50 gramos) (En Revisión)

3.3. Diagrama de Bloques Nivel 1

Billetera Inteligente

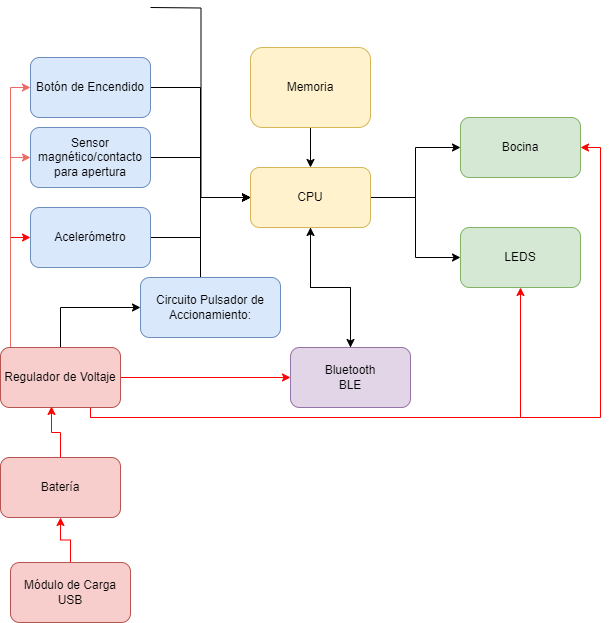
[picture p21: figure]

3.3.1. Búsqueda de Posibles Componentes

Microcontroladores

Componente | Precio | Voltaje | Corriente | Ventajas | Desventajas
ESP32 WROOM 32 | 20-40k | 2.7V-3.6V | Corriente típica de operación: 80mA | Integración de Wi-Fi y Bluetooth en un solo chip. Amplio soporte de GPIOs y periféricos. Muy popular y ampliamente soportado por la comunidad. | Mayor consumo de energía comparado con otros microcontroladores sin Wi-Fi/Bluetooth. Tamaño relativamente grande para aplicaciones ultracompactas.
Nordic nRF52840 | $5.30-$5.50 USD | 1.7V-5.5V | Corriente típica de operación: Bluetooth 3.83-16.40 mA CPU: 2.8 – 5.2 mA | Muy bajo consumo de energía, ideal para aplicaciones alimentadas por batería. Excelente rendimiento en comunicaciones Bluetooth Low Energy (BLE). Alta integración de periféricos, incluyendo soporte para USB. | Menos potente en procesamiento que el ESP32. Difícil de conseguir.
ESP32-S3 | 20000-40000 COP | 3-3.6V

ESP32 WROOM 32 : https://www.mouser.com/datasheet/2/891/esp-wroom-32_datasheet_en-1223836.pdf

Nordic nRF52840: https://infocenter.nordicsemi.com/pdf/nRF52840_PS_v1.1.pdf

ESP32-S3 : https://www.espressif.com/sites/default/files/documentation/esp32-s3_datasheet_en.pdf

Acelerómetro

MPU-6050 | 10000-15000 COP | 2.375V-3.46V | Corriente Operacional del: Acelerómetro: 500uA Giroscopio: 3.6mA | Integra acelerómetro y giroscopio, lo que permite la detección de movimiento en 6 ejes. Compatible con I2C, lo que facilita la integración con otros microcontroladores. Amplia comunidad de soporte y ejemplos de código disponibles. | Consumo de energía relativamente alto para aplicaciones alimentadas por batería. Sin características de bajo ruido o alta precisión en comparación con otros sensores.
ADXL345 | 7000-12000 COP | 2V-3.6V | 30uA – 150 uA (2.5V) | Bajo consumo de energía, ideal para aplicaciones alimentadas por batería. Amplio rango de ±2g, ±4g, ±8g, ±16g, configurable según la aplicación. Comunicación por I2C y SPI, facilitando la integración. | No es el más preciso en comparación con otros acelerómetros más avanzados. Tecnología más antigua, aunque sigue siendo ampliamente utilizada.

MPU6050 : https://www.alldatasheet.es/datasheet-pdf/download/517744/ETC1/MPU-6050.html

ADXL345: https://www.analog.com/media/en/technical-documentation/data-sheets/adxl345.pdf

LEDs

Leds SMD 0805 | 300 COP | 2.7v-3.7v | 25 mA | Tamaño compacto, ideal para aplicaciones donde el espacio es limitado. Disponible en una variedad de colores. Bajo costo y ampliamente disponible. | Brillo limitado en comparación con LEDs más grandes. Requiere una cuidadosa soldadura debido a su pequeño tamaño.
Leds SMD 5050 | 400 COP | 2V-3.6V | 60-75 mA | Alto brillo, adecuado para iluminación y efectos visuales. Capaz de emitir varios colores (RGB) en un solo paquete. Relativamente fácil de soldar debido a su tamaño. | Consumo de energía más alto debido a los múltiples chips. Ocupa más espacio en la PCB.
Leds SMD 3528 | 300 COP | 1.7V-2.4V | 50 mA | Tamaño intermedio, adecuado para aplicaciones de señalización y decoración. Disponible en varios colores, incluyendo opciones de alto brillo. Más eficiente que los LEDs 5050 en términos de consumo de energía por chip | Menos brillante que los LEDs 5050. Menor gama de colores comparado con LEDs RGB.

Led SMD 0805: https://www.mouser.com/datasheet/2/143/17-21-BHC-AP1Q2-3T_datasheet-51933.pdf

Led SMD 5050: https://www.iled.com/class/INNOVAEditor/assets/YeniDatasheets/4050-4055-4057.pdf

Led SMD 3528: https://www.sigmaelectronica.net/wp-content/uploads/2018/08/LED-3528BLANCO.pdf

Alimentación

Batería de litio-polímero | 25000-30000 COP | 3.7v | 500-1000 mAh | Alta densidad de energía, lo que permite una mayor capacidad en un tamaño pequeño. Forma flexible, disponible en diferentes formas y tamaños, ideal para aplicaciones compactas. Peso ligero, adecuado para dispositivos portátiles. | Requiere un manejo cuidadoso para evitar sobrecargas o sobre-descargas, que pueden causar daños. Vida útil limitada en comparación con otras baterías recargables. Puede ser más cara que otras opciones de baterías.

Batería Li-Po: https://www.zamux.co/bateria-recargable-litio-37v-500ma

Módulo de Carga

Módulo de carga TP4056 | 4000 COP | Input supply voltage: 4.25 – 6.5V | Input supply current: 35uA – 2 mA | Muy económico y ampliamente disponible. Configurable para diferentes corrientes de carga mediante la modificación de una resistencia. Fácil de integrar en proyectos DIY debido a su tamaño compacto. | Sin protección integrada por defecto (aunque hay versiones con protección). La corriente de carga puede ser limitada para baterías de mayor capacidad. Requiere soldadura si se necesita ajustar la corriente de carga.
Módulo de carga MCP73831 | 18000 COP | Input supply voltage: 3.75 – 6V | Input supply current: 510uA – 1.5 mA | Bajo consumo en reposo, ideal para aplicaciones de bajo consumo de energía. Muy eficiente en la gestión de la carga, prolongando la vida útil de la batería. Pequeño y fácil de integrar en PCB personalizadas. | Corriente de carga más baja (hasta 500 mA), lo que puede ser una limitación para baterías más grandes. Puede requerir componentes externos adicionales para ajustar el circuito.

TP4056: https://radioremont.com/wa-data/public/shop/products/32/33/3332/attachments/TP4056.pdf

MCP73831: https://www.alldatasheet.es/datasheet-pdf/download/305677/MICROCHIP/MCP73831.html

Pulsador

SW 4P NO | 400 COP | <42 V | <50mA | Tamaño pequeño, bajo costo. | Su tamaño puede dificultar la experiencia de usuario.

SW 4 Pines: https://cdn.soselectronic.com/productdata/f4/94/44a0b902/0862-8101.pdf

Mosfet Tipo N

2N7002 | 600 COP | VGS (th): 1V to 2.5V | I DSS: 1 to 500 uA | Tamaño pequeño, bajo costo.

2N7002: https://www.diodes.com/assets/Datasheets/ds11303.pdf

Mosfet Tipo P

FDN340P | 300 COP | VGS (th): -0.4V to -1.5V | I DSS: 1 to 10 uA | Tamaño pequeño, bajo costo. | .

FDN340P: https://www.onsemi.com/pdf/datasheet/fdn340p-d.pdf

Resistencias:

RES 1206 220 Ohm | 500 COP | Max 3.3V | Max 15mA
RES 1206 10k Ohm | 500 COP | Max 3.3V | Max 330uA
RES 1206 1M Ohm | 500 COP | Max 3.3V | Max 3,3uA

Sensor de Apertura

Reed Switch ORD213 | 1200 COP | < 24 V | <100mA | Tamaño pequeño, bajo costo. | Requiere un imán/campo magnético al otro extremo para su activación/desactivación.

ORD213: https://standexelectronics.com/wp-content/uploads/OKI_Reed_Switch_ORD213.pdf

Regulador de Voltaje

Regulador de Voltaje 3.3V

Bocina

Bocina piezoeléctrica SMD: CMT-2020 | 2-8k | 3v-12v | 1-10mA | Tamaño pequeño, bajo consumo de energía, bajo costo | No tiene un volumen muy alto, el sonido puede no ser de tan alta calidad

Diodos

1N4007 SMD | 200 COP | 0.7V | Average Forward Rectifier Current: 100mA | Tamaño pequeño, bajo consumo de energía, bajo costo

1N4007: https://www.alldatasheet.es/datasheet-pdf/download/209682/FCI/1N4007.html

3.4.2 Diagrama de Bloques Nivel 2

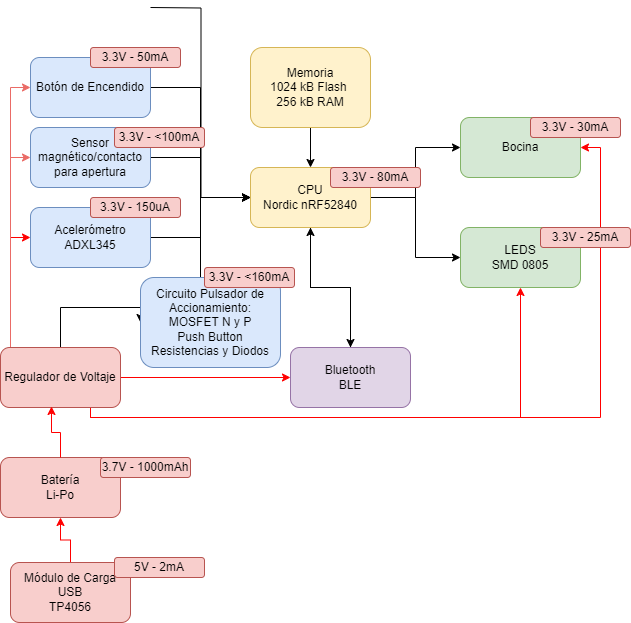
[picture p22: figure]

Fase 4: Diseño de Esquemáticos V1

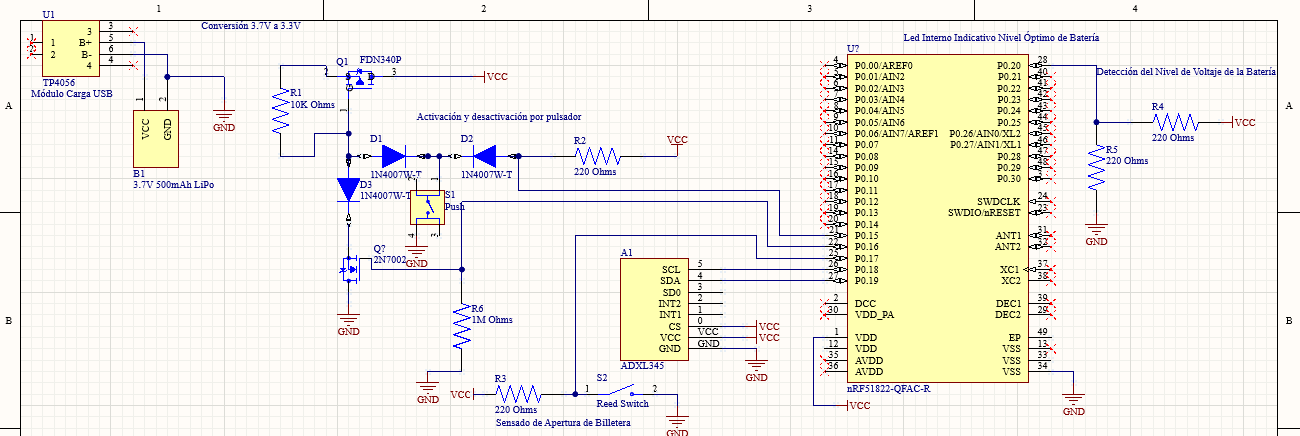
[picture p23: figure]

Fase 3: Desarrollo del concepto y prueba

A) Billetera Inteligente

1. Detalles de Marketing e Ingeniería

Marketing:

Identificación del Público Objetivo:

Jóvenes adultos y profesionales: Buscan tecnología innovadora, practicidad y seguridad.

Viajeros frecuentes: Valorarán las funciones de rastreo y seguridad en sus desplazamientos.

Aficionados a la tecnología: Adoptan rápidamente nuevos gadgets y buscan productos con características avanzadas.

Estrategia de Comunicación:

Redes sociales: Crear contenido atractivo y visualmente impactante para plataformas como Instagram, TikTok y Facebook.

Influencer marketing: Colaborar con influencers tecnológicos y de estilo de vida para llegar a un público más amplio.

Publicidad: Tiendas de tecnología y convenios con marcas de billeteras.

Canales de Venta:

Tiendas online: Vender a través de la propia tienda online y Marketplaces como Amazon, Mercado Libre, etc.

Tiendas físicas: Colaborar con tiendas de electrónica y accesorios de moda.

Distribuidores especializados: Llegar a un público más nicho a través de tiendas especializadas en tecnología.

Mensajes Clave:

Seguridad: Protección frente a robos y pérdidas.

Innovación: Tecnología de vanguardia y funcionalidades novedosas.

Conveniencia: Pagos sin contacto, organización de tarjetas y acceso a información importante.

Estilo: Diseño elegante y moderno que complementa cualquier atuendo.

Componentes por integrar se están por definirse

19. Mercado Objetivo
- Jóvenes adultos y profesionales: Buscan tecnología innovadora, practicidad y seguridad.
- Viajeros frecuentes: Valorarán las funciones de rastreo y seguridad en sus desplazamientos.
- Aficionados a la tecnología: Adoptan rápidamente nuevos gadgets y buscan productos con características avanzadas.
20. Beneficios
- Seguridad:
  - Protección contra acceso no autorizado
  - Alarma de distancia
  - Detección de caídas accidentales
  - Localización precisa en caso de pérdida (Evaluación Pendiente)
- Funcionalidad:
  - Integración con aplicación móvil
  - Comunicación via Bluetooth
  - Estadísticas en tiempo real: (Fecha y hora de apertura, movimientos anormales, registro de acceso no autorizado, registro de ubicación/última ubicación disponible)
- Ergonomía:
  - Pagos sin contacto
  - Tamaño reducido para integración en cualquier billetera
- Durabilidad:
  - BLE (Bluetooth Low Energy): Larga duración de la batería
21. ¿Cómo reaccionarían los consumidores al producto?
22. ¿Cómo se producirá el producto?
23. ¿Qué costo tendrá producirlo?
24. Encuestas a consumidores potenciales

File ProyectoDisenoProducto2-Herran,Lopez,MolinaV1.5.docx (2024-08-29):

Proyecto Diseño de Producto 2

Estudiantes:

Juan Sebastián Herrán

Josh López

Sergio Molina

Asignatura:

Diseño de Producto 2

Universidad Sergio Arboleda


Escuela de Ciencias Exactas e Ingeniería

Ingeniería Electrónica

2024

Fase 1: Lluvia de Ideas

Producto | Ingeniería de Producto | | | Análisis de Mercado | | Restricciones
| ¿Se puede desarrollar? ¿Cómo? | ¿Es viable desarrollarlo? | | ¿A quién le interesa? | ¿Por qué sería llamativo? ¿Es una necesidad, una oportunidad o una solución? | A) Conectividad a la nube B) Batería C) Activación sin contactos mecánicos
| | Beneficios | Desventajas
Billetera Inteligente Ingeniería de Producto Análisis de Mercado Cumple Restricciones | Sí: Bloqueo RFID Conexión Wi-Fi /BLE GPS Alarma de Distancia Acelerómetro | Seguridad: Protección contra pérdidas y robos. Funcionalidad: Integración con otras tecnologías y dispositivos. Comodidad: Organización y pagos sin contacto | Complejidad (Integración de diferentes componentes en espacio reducido) Costos Bajo consumo de batería | Viajeros Frecuentes Estudiantes Profesionales Early Adopters | Es llamativo por las mejoras en seguridad y las nuevas funcionalidades que puede ofrecer. En Colombia casi no hay productos en el mercado. Representa una solución frente a robos en pro de la protección de los datos personales. | A) Sí B) Sí C) Sí
Chip Detector para ropa Ingeniería de Producto Análisis de Mercado Cumple Restricciones | Sí: Tecnología RFID (Chips y Lector) Conectividad Wi-Fi Pantalla Base de Datos | Inventario Preciso y Gestión eficiente Rastreo del Uso de cada Prenda Ahorro de Tiempo de selección de atuendos Recomendaciones personalizadas | Miniaturización y durabilidad de los chips Adaptación en la Ropa y Diseño a prueba de daños Software de Gestión para almacenamiento de datos en la nube y escalabilidad | Personas que buscan optimizar el uso de ropa, recibir sugerencias y reducir el tiempo de selección de ropa Personas que quieren ahorrar tiempo y esfuerzo comprando ropa Tiendas y fabricantes de ropa | Es llamativo porque brinda eficiencia, personalización e innovación implementando pequeños chips en la ropa. En varias tiendas de ropa de Colombia se utiliza esta tecnología. Representa una solución para la gestión del inventario y el tiempo que demora seleccionar un atuendo cada día. | A) Sí B) Sí C) Sí
Sistema de seguridad para maletas Ingeniería de Producto Análisis de Mercado Cumple Restricciones | No: Sensores magnéticos/Contacto Bocina Tecnología Bluetooth/Wifi | Seguridad contra robos y pérdidas Monitoreo de la maleta | Duración y Consumo Batería Colocación y Activación del Sistema Complejidad para el diseño e implementación del Sistema a prueba de cualquier tipo de robo Ej. Rotura de la maleta | Personas que buscan proteger sus pertenencias y/o llevan objetos valiosos | No es llamativo frente a un candado. Existen múltiples alternativas en el mercado. Representa una solución para los continuos robos de las pertenencias dentro de las maletas | A) Sí B) Sí C) Sí
Sistema de alarma para cocinas Ingeniería de Producto Análisis de Mercado Cumple Restricciones | Sí: Sensores de Gas/Humo/ Calor Mecanismo de cerrado de válvula Alarma sonora/visual Notificación Remota: Conectividad Wi-Fi | Mayor seguridad Tranquilidad frente a la no atención de la cocina o a encontrarse fuera del hogar Automatización del cierre de la válvula de gas Integración con otras tecnologías Detección temprana de fugas de gas y/o incendios Visualización de datos | Duración y Consumo Batería Sensado Preciso y Falsas Alarmas Mantenimiento Ubicación y Activación del Sistema Costo | Personas ocupadas/olvidadizas Personas que buscan proteger su hogar de fugas de gas y/o incendios | Es llamativo al presentar una solución, planteada como de bajo costo, que permite detectar con antelación y actuar de manera automática. Representa una solución para las fugas de gas y/o incendios, así como para el cierre automático de la válvula de gas. | A) Sí B) En Duda C) Sí
Sistema detector de consumo (ropa, comida) - . Ingeniería de Producto Análisis de Mercado No Cumple Restricciones | Sí: Conectividad a Internet Cámaras de alta resolución Visión Artificial | Control de inventario de ropa, personalizaciones etc. Control del inventario de comida, evita la perdida de algún producto y reduce los gastos del usuario en algunos casos Control del inventario de comida, control de salud y control de gastos en comida | Complejidad: Requiere mucho tiempo de desarrollo. Requiere diseñar y probar un sistema avanzado de detección, a prueba de fallas, en muy poco tiempo. Altos Costos | Personas que tengan bastante ropa/comida Personas que sean descuidadas o desorganizadas, empresas con un alto nivel de inventario Personas que quieran o requieran un control más sano del consumo de la comida actual | Es llamativo al presentar una utilidad para el control del inventario, sin importar cuál sea. Representa una oportunidad para controlar el uso de la ropa, el consumo de comida, el control de gastos, etc. | A) Sí B) No C) Sí
Sistema detector de disponibilidad de restaurantes Ingeniería de Producto Análisis de Mercado Cumple Restricciones | Sí: Conectividad Wi-Fi GPS (Datos de Ubicación) Aplicación Móvil Base de Datos | Menor tiempo de búsqueda de restaurantes disponibles Mayor Ingreso a Restaurantes | Simplicidad Beneficios principalmente brindados desde la nube Detección de presencia (mesa disponible/no disponible) | Personas que quieren localizar restaurantes libres en menor tiempo Restaurantes que quieren atraer clientes de manera efectiva | Es llamativo al presentar una solución innovadora y de bajo costo que se puede implementar en cualquier mesa y en cualquier restaurante, para atraer más clientela. Representa una solución para localizar los restaurantes con disponibilidad de manera rápida y efectiva. | A) Sí B) Sí C) En Duda
Espejo inteligente - . Ingeniería de Producto Análisis de Mercado No Cumple Restricciones | No: Pantalla Sensores Cámara: Vision Artificial IoT | Sencillez Estética Ahorro de Tiempo para arreglarse | Alta Complejidad Altos Costos por unidad Alto Precio | Todas las personas | Es llamativo al presentar una herramienta tecnológica para mejorar el estilo y la estética de las personas. Representa una oportunidad para ahorrarse tiempo arreglándose y recibir los mejores consejos. | A) Sí B) No C) Sí
Módulo GPS portable - . Ingeniería de Producto Análisis de Mercado No Cumple Restricciones | No: GPS Conectividad Wi-Fi | Seguridad Tranquilidad, Movilización Monitoreo de la Ubicación | Costo de producción vs. Precio Atractivo Muy Pocas funcionalidades Simplicidad Complejidad en la Conexión a Internet y a la nube Bajo consumo de batería | Niños | Es llamativo al presentar una herramienta tecnológica, planteada de bajo costo, para el monitoreo de la ubicación. Representa la atención a la necesidad del monitoreo constante de la ubicación de los niños. | A) Sí B) Sí C) No
Alacena Inteligente - . Ingeniería de Producto Análisis de Mercado No Cumple Restricciones | No: Sensores de Peso Actuadores para ubicar objetos Revisión de alimentos faltantes o cerca de vencerse | Reducción del desperdicio de alimentos Mejora de la organización Alimentación saludable Ahorro de tiempo | Complejidad Altos Costos vs. Proceso Manual Tamaño Tiempo de Desarrollo, Iteraciones y Pruebas Potencia Necesaria desde Alimentación del Sistema Requiere espacios fijos para los alimentos | Personas que quieren ahorrar tiempo en la cocina, y con gran capacidad adquisitiva. | Es llamativo al presentar una herramienta tecnológica para la organización automática de la alacena. Su alto precio no sería llamativo. Representa una oportunidad para ahorrarse tiempo en el proceso. | A) Sí B) No C) No
Estuche Gafas Inteligente - . Ingeniería de Producto Análisis de Mercado Cumple Restricciones | Sí: Tecnología Bluetooth Pantalla | Comodidad: Carga inalámbrica y sencilla. Funcionalidades Adicionales a un estuche convencional Integración: Se integra con otras tecnologías, como asistentes virtuales. | Pocas Funcionalidades Limitada Recolección de Estadísticas Complejidad para funcionalidades específicas | Personas que portan gafas que quieren un producto innovador Early-adopters | Es llamativo al presentar una innovación frente al estuche convencional. Representa una oportunidad para integrar la tecnología al estuche de gafas y conectarlo al IoT. | A) Sí B) Sí C) Sí

Análisis Criterios Iniciales:

DP2-T0-Herran,Lopez,Molina.xlsx (https://universidadsergioarboleda-my.sharepoint.com/:x:/g/personal/josh_lopez01_usa_edu_co/EcgmHX4n6xtBkdCwMJmsrzgBQwG7WUzlyEpB4xwgIX4yPQ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)

Fase 2: Filtrado de Ideas

Producto | ¿Es amplio el mercado objetivo? | ¿El mercado objetivo realmente se beneficiará del producto? | ¿Es técnicamente viable fabricar este producto? | ¿Generaría beneficios este producto en el tiempo?
Billetera Inteligente | Por supuesto. Todos los estudiantes y profesionales manejan una billetera para cuidar su dinero y documentos. | Por supuesto. El producto les garantizaría mayor seguridad en cuanto a la posibilidad de extraviar o ser víctimas de robo de su billetera. | Por supuesto. Se necesitarían componentes de bajo consumo y tamaño reducido. | Entre más popular se vuelva el producto, se generará una mayor rentabilidad, planteando un bajo costo y múltiples funcionalidades novedosas.
Chip Detector para ropa | No lo suficiente, pues solo las personas interesadas en la innovación del producto estarían dispuestas a comprarlo. Además, muchas tiendas de ropa ya implementan esta tecnología. | Por supuesto. A los usuarios les permitiría conocer la frecuencia de uso de su ropa y reducir tiempo al obtener recomendaciones de combinaciones de prendas para utilizar cada día. A las tiendas les permitiría un óptimo manejo del stock. | Por supuesto. Implica un menor costo en términos de tecnología RFID, pero todas las funcionalidades vendrían ligadas al software. | Depende de lo popular que se vuelva y lo útil que pueda llegar hacer, por lo que, al no poder producirse en masa, no generaría mucha rentabilidad.
Sistema de alarma para cocinas | Por supuesto. Todos los hogares podrían adquirir e implementar un sistema de bajo costo para sus cocinas. | Por supuesto. Desde el cerrado automático de la válvula de gas hasta el sistema de alarma y el monitoreo de datos, el producto presenta múltiples beneficios. | Por supuesto. Sin embargo, necesitaría una serie de pruebas para determinar los mejores sensores de bajo costo, y reducir el tamaño mientras siga cumpliendo sus requerimientos funcionales. | Depende tanto de su popularidad como principalmente de su precio, por lo que puede no generar mucha rentabilidad.
Sistema detector de nivel de llenado de restaurantes | Por supuesto. Todos los restaurantes pueden implementar el sensor que permite detectar si la mesa está ocupada, y conectar los datos a una aplicación móvil. Además, muchos empleados que buscan restaurante con disponibilidad para almorzar se verían beneficiados con la aplicación. | Por supuesto. En términos de eficiencia para encontrar restaurante disponible, y los propios restaurantes para obtener mayor clientela. | Por supuesto. No obstante, la mayor dificultad radica en detectar con certeza si una mesa se encuentra ocupada (sensor de presencia). | Depende de la cantidad de restaurantes que implementen dicha tecnología, por lo que en tanto se vuelva popular, puede generar rentabilidad. Sin embargo, no muchos restaurantes tenderían a apostar por el producto, pues el mayor beneficio recae en el cliente.

Ideas Seleccionadas:

1. Billetera Inteligente
2. Sistema de Alarma para cocinas

Fase 3: Desarrollo del concepto y prueba

3.1. Encuestas

1. Sistema de alarma para cocinas


Link de la encuesta: https://forms.gle/PwD4ogpmBEbutgUVA

2. Billetera inteligente


Link de la encuesta: https://forms.gle/VZ8JmRUWkLo8zy4EA

Fase 3: Desarrollo del concepto y prueba

3.2. Requerimientos

A) Billetera Inteligente

Requerimientos Funcionales

1. Detección de apertura para protección con Intrusiones (Determinar si el acceso es o no autorizado)
2. Notificación de Alejamiento de la billetera (Desconexión por Distancia mayor a 10 metros)
3. Autonomía Energética – 24 horas de batería
4. Detección de caída (Por definir)
5. Comunicación vía Bluetooth Low Energy (BLE)
6. Almacenamiento de datos históricos (X Megabytes) (Por definir)
7. Registro de actividades (apertura, movimientos sospechosos o no sospechosos) (12 horas de registro)
8. Visualización de datos históricos en tiempo real (1 min de retraso)
9. Alerta sonora (1-0)
10. Señalización visual apertura o cierre – Leds (1-0)
11. Activación desde aplicación móvil (1-0)
12. Notificación del estado de batería – Leds (Rojo-Verde)
13. Registro de movimientos bruscos (Por definir)
14. Función de autoapagado para ahorro de energía (1 min sin conexión al celular)
15. Botón de encendido/apagado (1-0)
16. Botón de desbloqueo manual (1-0)
17. Temporizador de apertura de la billetera (1 min)
18. Ubicación GPS (Por definir si se incluye)

Requerimientos No Funcionales

1. Tamaño Reducido (6x3x1cm) (Por definir)
2. Latencia de comunicación aceptable (10 ms)
3. Bajo consumo de energía (x W) (Por definir)
4. Costo asequible ($60000) (Por definir)
5. Seguridad de la información – Restricción contra intrusiones (Protocolo X)

(Por definir)

6. Copias de seguridad automáticas
7. Durabilidad y resistencia
8. Interfaz de usuario intuitiva
9. Peso reducido (x gramos) (Por definir)

3.3. Diagrama de Bloques Nivel 1

Billetera Inteligente

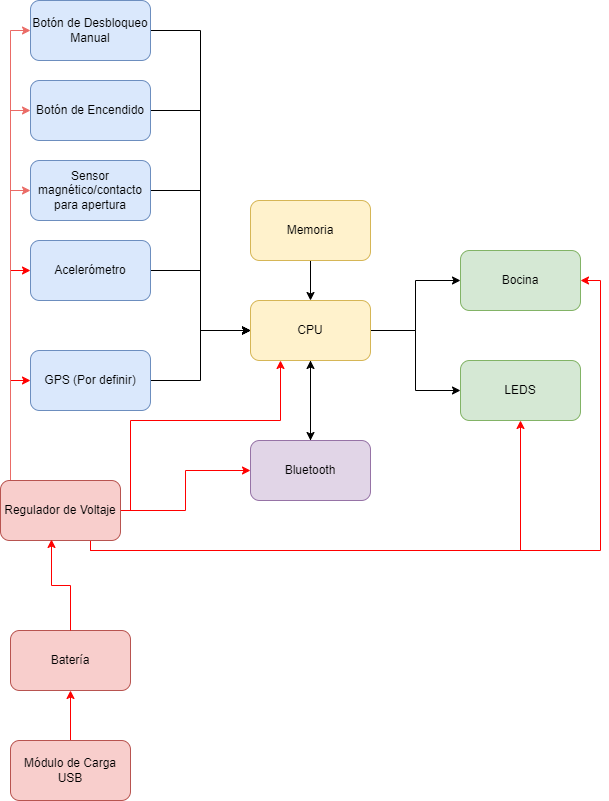
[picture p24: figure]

3.4. Diagrama de Bloques Nivel 2

1. Alimentación: Batería 3.7V

Regulación Voltaje 3.7V a 3.3V

a) Opción 1: Diodo Zener 1N4728A - VZ= 3.3V


b) Opción 2: Diodo Zener y Transistor BJT


Fase 3: Desarrollo del concepto y prueba

A) Billetera Inteligente

1. Detalles de Marketing e Ingeniería

Marketing:

Identificación del Público Objetivo:

Jóvenes adultos y profesionales: Buscan tecnología innovadora, practicidad y seguridad.

Viajeros frecuentes: Valorarán las funciones de rastreo y seguridad en sus desplazamientos.

Aficionados a la tecnología: Adoptan rápidamente nuevos gadgets y buscan productos con características avanzadas.

Estrategia de Comunicación:

Redes sociales: Crear contenido atractivo y visualmente impactante para plataformas como Instagram, TikTok y Facebook.

Influencer marketing: Colaborar con influencers tecnológicos y de estilo de vida para llegar a un público más amplio.

Publicidad: Tiendas de tecnología y convenios con marcas de billeteras.

Canales de Venta:

Tiendas online: Vender a través de la propia tienda online y Marketplaces como Amazon, Mercado Libre, etc.

Tiendas físicas: Colaborar con tiendas de electrónica y accesorios de moda.

Distribuidores especializados: Llegar a un público más nicho a través de tiendas especializadas en tecnología.

Mensajes Clave:

Seguridad: Protección frente a robos y pérdidas.

Innovación: Tecnología de vanguardia y funcionalidades novedosas.

Conveniencia: Pagos sin contacto, organización de tarjetas y acceso a información importante.

Estilo: Diseño elegante y moderno que complementa cualquier atuendo.

Ingeniería:

Opción Microcontrolador 1: Esp8586 a 3.3v tiene WiFi 802.11. Precio 10k-15k

Modulo bluetooth hc-05 precio 20k+

Opción Microcontrolador 2: ESP32 Precio 20k-40k

Batería de polímero de litio LP503040: 3.7v 500-1000 mAh, Precio 12k-40k

GPS: Ublox NEO-6M voltaje 2.7v - 3.6v, corriente de consumo 45mA, Precio 32k-60k

Acelerómetro y giroscopio: MPU-6050 voltaje 2.3v-3.4v, corriente de consumo 3.9mA Precio 8k-20k

Módulo de carga: TP4056 voltaje de operación 5v (entrada USB), Precio 4k-12k

Leds SMD 0805: leds de montaje superficial, pequeños con consumo de 20mA y voltaje entre 2V y 3.2V, Precio 400-2k

Bocina piezoeléctrica SMT-0825: voltaje 3v-5v, corriente 20mA, Precio 2k-8k

Mecanismo de bloqueo remoto: solenoide miniatura voltaje 3v-5v, corriente 100mA-200mA, Precio 8k-40k

Regulador de voltaje: regulador LDO, MCP1700 Precio 2k-6k

19. Mercado Objetivo
- Jóvenes adultos y profesionales: Buscan tecnología innovadora, practicidad y seguridad.
- Viajeros frecuentes: Valorarán las funciones de rastreo y seguridad en sus desplazamientos.
- Aficionados a la tecnología: Adoptan rápidamente nuevos gadgets y buscan productos con características avanzadas.
20. Beneficios
- Seguridad:
  - Protección contra acceso no autorizado
  - Alarma de distancia
  - Detección de caídas accidentales
  - Localización precisa en caso de pérdida (Evaluación Pendiente)
- Funcionalidad:
  - Integración con aplicación móvil
  - Comunicación via Bluetooth
  - Estadísticas en tiempo real: (Fecha y hora de apertura, movimientos anormales, registro de acceso no autorizado, registro de ubicación/última ubicación disponible)
- Ergonomía:
  - Pagos sin contacto
  - Tamaño reducido para integración en cualquier billetera
- Durabilidad:
  - BLE (Bluetooth Low Energy): Larga duración de la batería
21. ¿Cómo reaccionarían los consumidores al producto?
22. ¿Cómo se producirá el producto?
23. ¿Qué costo tendrá producirlo?
24. Encuestas a consumidores potenciales

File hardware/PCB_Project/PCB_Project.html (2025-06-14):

Reporting Options

# File in Newer Format

Date | : | 19/09/2024
Time | : | 6:34:21 p. m.
Project name | : | C:\Users\Labing\Downloads\PCB_DP2-V2\PCB_DP2\PCB_Project\PCB_Project.PrjPcb
Schematic documents | : | Sheet2.SchDoc

Version | Warning
22.3.0 | Custom diff pair suffixes are not supported in this version.

These files were generated in a later version of Altium Designer. Be aware that some data may have been added through functionality not available in your current version and will therefore not be available to you.

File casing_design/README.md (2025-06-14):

# Casing Design V1.0

Casing Design using Fusion 360.

## Top View
Top

## Side View
Side

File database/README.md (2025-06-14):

## Database Design using MongoDB Atlas

[DbDocs](https://dbdocs.io/joshmessi10/smart_wallet_database)

Database

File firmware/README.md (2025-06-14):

# Firmware

Programming the nRF51822 chip.

Previous Test

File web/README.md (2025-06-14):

## Webpage Design (Google Cloud)

Design and Launch of Smart Wallet Webpage using Google Cloud.

## 🧠 Features

- 📊 **States Visualization**:
  - 📶 BLE Connection  
  - 🔋 Battery Level  
  - 📏 Distance from Phone  
  - 🗺️ Last Location Registered

- 🚨 **Security Alerts and Logs**
- 🕓 **Connection History**
- ℹ️ **About the Software/Hardware**

Webpage

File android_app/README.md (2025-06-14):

# Android App Design

Designing and Launching an Android App to send Smart Wallet data to website using Android Studio.

## 🧠 Features

- 🔌 Manual Connection/Disconnection to Website & Smart Chip

- 🔋 Battery Level Reading

- 🔊 Buzzer State Visualization

- 🤸‍♂️ Fall Detection

- 👜 Open/Close Wallet Detection

Android App

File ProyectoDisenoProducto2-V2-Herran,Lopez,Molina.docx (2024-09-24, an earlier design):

Proyecto Diseño de Producto 2

Estudiantes:

Juan Sebastián Herrán

Josh López

Sergio Molina

Asignatura:

Diseño de Producto 2

Universidad Sergio Arboleda


Escuela de Ciencias Exactas e Ingeniería

Ingeniería Electrónica

2024

Fase 1: Lluvia de Ideas

Producto | Ingeniería de Producto | | | Análisis de Mercado | | Restricciones
| ¿Se puede desarrollar? ¿Cómo? | ¿Es viable desarrollarlo? | | ¿A quién le interesa? | ¿Por qué sería llamativo? ¿Es una necesidad, una oportunidad o una solución? | A) Conectividad a la nube B) Batería C) Activación sin contactos mecánicos
| | Beneficios | Desventajas
Billetera Inteligente Ingeniería de Producto Análisis de Mercado Cumple Restricciones | Sí: Bloqueo RFID Conexión Wi-Fi /BLE GPS Alarma de Distancia Acelerómetro | Seguridad: Protección contra pérdidas y robos. Funcionalidad: Integración con otras tecnologías y dispositivos. Comodidad: Organización y pagos sin contacto | Complejidad (Integración de diferentes componentes en espacio reducido) Costos Bajo consumo de batería | Viajeros Frecuentes Estudiantes Profesionales Early Adopters | Es llamativo por las mejoras en seguridad y las nuevas funcionalidades que puede ofrecer. En Colombia casi no hay productos en el mercado. Representa una solución frente a robos en pro de la protección de los datos personales. | A) Sí B) Sí C) Sí
Chip Detector para ropa Ingeniería de Producto Análisis de Mercado Cumple Restricciones | Sí: Tecnología RFID (Chips y Lector) Conectividad Wi-Fi Pantalla Base de Datos | Inventario Preciso y Gestión eficiente Rastreo del Uso de cada Prenda Ahorro de Tiempo de selección de atuendos Recomendaciones personalizadas | Miniaturización y durabilidad de los chips Adaptación en la Ropa y Diseño a prueba de daños Software de Gestión para almacenamiento de datos en la nube y escalabilidad | Personas que buscan optimizar el uso de ropa, recibir sugerencias y reducir el tiempo de selección de ropa Personas que quieren ahorrar tiempo y esfuerzo comprando ropa Tiendas y fabricantes de ropa | Es llamativo porque brinda eficiencia, personalización e innovación implementando pequeños chips en la ropa. En varias tiendas de ropa de Colombia se utiliza esta tecnología. Representa una solución para la gestión del inventario y el tiempo que demora seleccionar un atuendo cada día. | A) Sí B) Sí C) Sí
Sistema de seguridad para maletas Ingeniería de Producto Análisis de Mercado Cumple Restricciones | No: Sensores magnéticos/Contacto Bocina Tecnología Bluetooth/Wifi | Seguridad contra robos y pérdidas Monitoreo de la maleta | Duración y Consumo Batería Colocación y Activación del Sistema Complejidad para el diseño e implementación del Sistema a prueba de cualquier tipo de robo Ej. Rotura de la maleta | Personas que buscan proteger sus pertenencias y/o llevan objetos valiosos | No es llamativo frente a un candado. Existen múltiples alternativas en el mercado. Representa una solución para los continuos robos de las pertenencias dentro de las maletas | A) Sí B) Sí C) Sí
Sistema de alarma para cocinas Ingeniería de Producto Análisis de Mercado Cumple Restricciones | Sí: Sensores de Gas/Humo/ Calor Mecanismo de cerrado de válvula Alarma sonora/visual Notificación Remota: Conectividad Wi-Fi | Mayor seguridad Tranquilidad frente a la no atención de la cocina o a encontrarse fuera del hogar Automatización del cierre de la válvula de gas Integración con otras tecnologías Detección temprana de fugas de gas y/o incendios Visualización de datos | Duración y Consumo Batería Sensado Preciso y Falsas Alarmas Mantenimiento Ubicación y Activación del Sistema Costo | Personas ocupadas/olvidadizas Personas que buscan proteger su hogar de fugas de gas y/o incendios | Es llamativo al presentar una solución, planteada como de bajo costo, que permite detectar con antelación y actuar de manera automática. Representa una solución para las fugas de gas y/o incendios, así como para el cierre automático de la válvula de gas. | A) Sí B) En Duda C) Sí
Sistema detector de consumo (ropa, comida) - . Ingeniería de Producto Análisis de Mercado No Cumple Restricciones | Sí: Conectividad a Internet Cámaras de alta resolución Visión Artificial | Control de inventario de ropa, personalizaciones etc. Control del inventario de comida, evita la perdida de algún producto y reduce los gastos del usuario en algunos casos Control del inventario de comida, control de salud y control de gastos en comida | Complejidad: Requiere mucho tiempo de desarrollo. Requiere diseñar y probar un sistema avanzado de detección, a prueba de fallas, en muy poco tiempo. Altos Costos | Personas que tengan bastante ropa/comida Personas que sean descuidadas o desorganizadas, empresas con un alto nivel de inventario Personas que quieran o requieran un control más sano del consumo de la comida actual | Es llamativo al presentar una utilidad para el control del inventario, sin importar cuál sea. Representa una oportunidad para controlar el uso de la ropa, el consumo de comida, el control de gastos, etc. | A) Sí B) No C) Sí
Sistema detector de disponibilidad de restaurantes Ingeniería de Producto Análisis de Mercado Cumple Restricciones | Sí: Conectividad Wi-Fi GPS (Datos de Ubicación) Aplicación Móvil Base de Datos | Menor tiempo de búsqueda de restaurantes disponibles Mayor Ingreso a Restaurantes | Simplicidad Beneficios principalmente brindados desde la nube Detección de presencia (mesa disponible/no disponible) | Personas que quieren localizar restaurantes libres en menor tiempo Restaurantes que quieren atraer clientes de manera efectiva | Es llamativo al presentar una solución innovadora y de bajo costo que se puede implementar en cualquier mesa y en cualquier restaurante, para atraer más clientela. Representa una solución para localizar los restaurantes con disponibilidad de manera rápida y efectiva. | A) Sí B) Sí C) En Duda
Espejo inteligente - . Ingeniería de Producto Análisis de Mercado No Cumple Restricciones | No: Pantalla Sensores Cámara: Vision Artificial IoT | Sencillez Estética Ahorro de Tiempo para arreglarse | Alta Complejidad Altos Costos por unidad Alto Precio | Todas las personas | Es llamativo al presentar una herramienta tecnológica para mejorar el estilo y la estética de las personas. Representa una oportunidad para ahorrarse tiempo arreglándose y recibir los mejores consejos. | A) Sí B) No C) Sí
Módulo GPS portable - . Ingeniería de Producto Análisis de Mercado No Cumple Restricciones | No: GPS Conectividad Wi-Fi | Seguridad Tranquilidad, Movilización Monitoreo de la Ubicación | Costo de producción vs. Precio Atractivo Muy Pocas funcionalidades Simplicidad Complejidad en la Conexión a Internet y a la nube Bajo consumo de batería | Niños | Es llamativo al presentar una herramienta tecnológica, planteada de bajo costo, para el monitoreo de la ubicación. Representa la atención a la necesidad del monitoreo constante de la ubicación de los niños. | A) Sí B) Sí C) No
Alacena Inteligente - . Ingeniería de Producto Análisis de Mercado No Cumple Restricciones | No: Sensores de Peso Actuadores para ubicar objetos Revisión de alimentos faltantes o cerca de vencerse | Reducción del desperdicio de alimentos Mejora de la organización Alimentación saludable Ahorro de tiempo | Complejidad Altos Costos vs. Proceso Manual Tamaño Tiempo de Desarrollo, Iteraciones y Pruebas Potencia Necesaria desde Alimentación del Sistema Requiere espacios fijos para los alimentos | Personas que quieren ahorrar tiempo en la cocina, y con gran capacidad adquisitiva. | Es llamativo al presentar una herramienta tecnológica para la organización automática de la alacena. Su alto precio no sería llamativo. Representa una oportunidad para ahorrarse tiempo en el proceso. | A) Sí B) No C) No
Estuche Gafas Inteligente - . Ingeniería de Producto Análisis de Mercado Cumple Restricciones | Sí: Tecnología Bluetooth Pantalla | Comodidad: Carga inalámbrica y sencilla. Funcionalidades Adicionales a un estuche convencional Integración: Se integra con otras tecnologías, como asistentes virtuales. | Pocas Funcionalidades Limitada Recolección de Estadísticas Complejidad para funcionalidades específicas | Personas que portan gafas que quieren un producto innovador Early-adopters | Es llamativo al presentar una innovación frente al estuche convencional. Representa una oportunidad para integrar la tecnología al estuche de gafas y conectarlo al IoT. | A) Sí B) Sí C) Sí

Análisis Criterios Iniciales:

DP2-T0-Herran,Lopez,Molina.xlsx (https://universidadsergioarboleda-my.sharepoint.com/:x:/g/personal/josh_lopez01_usa_edu_co/EcgmHX4n6xtBkdCwMJmsrzgBQwG7WUzlyEpB4xwgIX4yPQ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)

Fase 2: Filtrado de Ideas

Producto | ¿Es amplio el mercado objetivo? | ¿El mercado objetivo realmente se beneficiará del producto? | ¿Es técnicamente viable fabricar este producto? | ¿Generaría beneficios este producto en el tiempo?
Billetera Inteligente | Por supuesto. Todos los estudiantes y profesionales manejan una billetera para cuidar su dinero y documentos. | Por supuesto. El producto les garantizaría mayor seguridad en cuanto a la posibilidad de extraviar o ser víctimas de robo de su billetera. | Por supuesto. Se necesitarían componentes de bajo consumo y tamaño reducido. | Entre más popular se vuelva el producto, se generará una mayor rentabilidad, planteando un bajo costo y múltiples funcionalidades novedosas.
Chip Detector para ropa | No lo suficiente, pues solo las personas interesadas en la innovación del producto estarían dispuestas a comprarlo. Además, muchas tiendas de ropa ya implementan esta tecnología. | Por supuesto. A los usuarios les permitiría conocer la frecuencia de uso de su ropa y reducir tiempo al obtener recomendaciones de combinaciones de prendas para utilizar cada día. A las tiendas les permitiría un óptimo manejo del stock. | Por supuesto. Implica un menor costo en términos de tecnología RFID, pero todas las funcionalidades vendrían ligadas al software. | Depende de lo popular que se vuelva y lo útil que pueda llegar hacer, por lo que, al no poder producirse en masa, no generaría mucha rentabilidad.
Sistema de alarma para cocinas | Por supuesto. Todos los hogares podrían adquirir e implementar un sistema de bajo costo para sus cocinas. | Por supuesto. Desde el cerrado automático de la válvula de gas hasta el sistema de alarma y el monitoreo de datos, el producto presenta múltiples beneficios. | Por supuesto. Sin embargo, necesitaría una serie de pruebas para determinar los mejores sensores de bajo costo, y reducir el tamaño mientras siga cumpliendo sus requerimientos funcionales. | Depende tanto de su popularidad como principalmente de su precio, por lo que puede no generar mucha rentabilidad.
Sistema detector de nivel de llenado de restaurantes | Por supuesto. Todos los restaurantes pueden implementar el sensor que permite detectar si la mesa está ocupada, y conectar los datos a una aplicación móvil. Además, muchos empleados que buscan restaurante con disponibilidad para almorzar se verían beneficiados con la aplicación. | Por supuesto. En términos de eficiencia para encontrar restaurante disponible, y los propios restaurantes para obtener mayor clientela. | Por supuesto. No obstante, la mayor dificultad radica en detectar con certeza si una mesa se encuentra ocupada (sensor de presencia). | Depende de la cantidad de restaurantes que implementen dicha tecnología, por lo que en tanto se vuelva popular, puede generar rentabilidad. Sin embargo, no muchos restaurantes tenderían a apostar por el producto, pues el mayor beneficio recae en el cliente.

Ideas Seleccionadas:

1. Billetera Inteligente
2. Sistema de Alarma para cocinas

Fase 3: Desarrollo del concepto y prueba

3.1. Encuestas

1. Sistema de alarma para cocinas


Link de la encuesta: https://forms.gle/PwD4ogpmBEbutgUVA

2. Billetera inteligente


Link de la encuesta: https://forms.gle/VZ8JmRUWkLo8zy4EA

Fase 3: Desarrollo del concepto y prueba

A) Billetera Inteligente

1. Detalles de Marketing e Ingeniería

Marketing:

Identificación del Público Objetivo:

Jóvenes adultos y profesionales: Buscan tecnología innovadora, practicidad y seguridad.

Viajeros frecuentes: Valorarán las funciones de rastreo y seguridad en sus desplazamientos.

Aficionados a la tecnología: Adoptan rápidamente nuevos gadgets y buscan productos con características avanzadas.

Estrategia de Comunicación:

Redes sociales: Crear contenido atractivo y visualmente impactante para plataformas como Instagram, TikTok y Facebook.

Influencer marketing: Colaborar con influencers tecnológicos y de estilo de vida para llegar a un público más amplio.

Publicidad: Tiendas de tecnología y convenios con marcas de billeteras.

Canales de Venta:

Tiendas online: Vender a través de la propia tienda online y Marketplaces como Amazon, Mercado Libre, etc.

Tiendas físicas: Colaborar con tiendas de electrónica y accesorios de moda.

Distribuidores especializados: Llegar a un público más nicho a través de tiendas especializadas en tecnología.

Mensajes Clave:

Seguridad: Protección frente a robos y pérdidas.

Innovación: Tecnología de vanguardia y funcionalidades novedosas.

Conveniencia: Pagos sin contacto, organización de tarjetas y acceso a información importante.

Estilo: Diseño elegante y moderno que complementa cualquier atuendo.

1. Mercado Objetivo
- Jóvenes adultos y profesionales: Buscan tecnología innovadora, practicidad y seguridad.
- Viajeros frecuentes: Valorarán las funciones de rastreo y seguridad en sus desplazamientos.
- Aficionados a la tecnología: Adoptan rápidamente nuevos gadgets y buscan productos con características avanzadas.
2. Beneficios
- Seguridad:
  - Protección contra acceso no autorizado
  - Alarma por Alejamiento
  - Detección de caídas accidentales
  - Localización precisa en caso de pérdida
- Funcionalidad:
  - Integración con aplicación móvil
  - Comunicación via Bluetooth
  - Estadísticas en tiempo real: (Fecha y hora de apertura, movimientos anormales, registro de acceso no autorizado, registro de ubicación/última ubicación disponible)
- Ergonomía:
  - Tamaño reducido para integración en cualquier billetera
- Durabilidad:
  - BLE (Bluetooth Low Energy): Larga duración de la batería

Fase 3: Desarrollo del concepto y prueba

3.2. Requerimientos

A) Billetera Inteligente

Requerimientos Funcionales

3. Detección de apertura para protección con Intrusiones (Determinar si el acceso es o no autorizado) (Estados On/Off)
4. Notificación de Alejamiento de la billetera (Desconexión por Distancia mayor a 10 metros)
5. Autonomía Energética – 12 horas de batería
6. Detección de caída (-1g=-9.81m/s²)
7. Comunicación vía Bluetooth Low Energy (Protocolo BLE – 2.4GHz)
8. Almacenamiento de datos históricos (500 kilobytes)
9. Registro de actividades (apertura, movimientos sospechosos o no sospechosos) (12 horas de registro)
10. Visualización de datos históricos en tiempo real (1 min de retraso)
11. Alerta sonora (Estados On/Off)
12. Señalización visual apertura o cierre – Leds (Estados On/Off)
13. Activación desde aplicación móvil (Estados On/Off)
14. Notificación del estado de batería – Leds (Rojo-Verde)
15. Registro de movimientos bruscos (Intervalo entre ±2g y ±4g =±19.62g - ±39.24 g)
16. Función de autoapagado para ahorro de energía (1 min sin conexión al celular)
17. Botón de encendido/apagado (Estados On/Off)
18. Botón de desbloqueo manual (Estados On/Off)
19. Temporizador de apertura de la billetera (1 min)
20. Señal sonora para localizar tu billetera (Estados On/Off)
21. Señalización batería cargada – Leds (Estados On/Off)

Requerimientos No Funcionales

1. Tamaño Reducido (6x3x0.16cm) (En Revisión)
2. Latencia de comunicación aceptable (10 ms – Protocolo BLE)
3. Bajo consumo de energía (Ej. 0.3 W en alto consumo) (En revisión)
4. Costo asequible ($60000) (En Revisión)
5. Seguridad de la información – Restricción contra intrusiones (Protocolo X)

(Conexión con cifrado BLE)

(Protocolo TLS/SSL para la aplicación móvil)

6. Copias de seguridad automáticas

(Disponibles en la aplicación para las últimas 48 horas)

7. Durabilidad y resistencia

(Materiales por definir)

8. Interfaz de usuario intuitiva

Paso 1: Registro en la aplicación móvil

Paso 2: Conexión de la billetera inteligente

Paso 3: Visualización de datos

9. Peso reducido (Por Definir)

3.3. Diagrama de Bloques Nivel 1

Billetera Inteligente


3.3.1. Búsqueda de Posibles Componentes

Microcontroladores

Componente | Precio | Voltaje | Corriente | Ventajas | Desventajas
ESP32 WROOM 32 | 20000-40000 COP | 2.7V-3.6V | Corriente típica de operación: 80mA | Integración de Wi-Fi y Bluetooth en un solo chip. Amplio soporte de GPIOs y periféricos. Muy popular y ampliamente soportado por la comunidad. | Mayor consumo de energía comparado con otros microcontroladores sin Wi-Fi/Bluetooth. Tamaño relativamente grande para aplicaciones ultracompactas.
Nordic nRF52840 QAAF | $10 USD | 1.7V-5.5V | Corriente típica de operación: Bluetooth 3.83-16.40 mA CPU: 2.8 – 5.2 mA | Muy bajo consumo de energía, ideal para aplicaciones alimentadas por batería. Excelente rendimiento en comunicaciones Bluetooth Low Energy (BLE). Alta integración de periféricos, incluyendo soporte para USB. | Menos potente en procesamiento que el ESP32. Más difícil de conseguir.
ESP32-S3 | 20000-40000 COP | 3-3.6V | 80-240mA | Mayor potencia de procesamiento, memoria y conectividad. | Mayor consumo de energía.
Nordic nRF51822 | $10 USD | 3.3V-5V | Corriente típica de operación: Bluetooth: 1.6mA-13mA Internal Radio Current Consumption: 7.8uA | Muy bajo consumo de energía, ideal para aplicaciones alimentadas por batería. Excelente rendimiento en comunicaciones Bluetooth Low Energy (BLE). | Menos potente en procesamiento que el ESP32. Difícil de conseguir. Menor cantidad de pines GPIO que en nRF52840.

ESP32 WROOM 32 : https://www.mouser.com/datasheet/2/891/esp-wroom-32_datasheet_en-1223836.pdf

Nordic nRF52840-DONGLE: https://infocenter.nordicsemi.com/pdf/nRF52840_PS_v1.1.pdf

ESP32-S3 : https://www.espressif.com/sites/default/files/documentation/esp32-s3_datasheet_en.pdf

Nordic nRF51822-DONGLE: nRF51x22 PS.book (nordicsemi.com) (https://infocenter.nordicsemi.com/pdf/nRF51822_PS_v3.1.pdf)

Acelerómetro

Componente | Precio | Voltaje | Corriente | Ventajas | Desventajas
MPU-6050 | 10000-15000 COP | 2.375V-3.46V | Corriente Operacional del: Acelerómetro: 500uA Giroscopio: 3.6mA | Integra acelerómetro y giroscopio, lo que permite la detección de movimiento en 6 ejes. Compatible con I2C, lo que facilita la integración con otros microcontroladores. Amplia comunidad de soporte y ejemplos de código disponibles. | Consumo de energía relativamente alto para aplicaciones alimentadas por batería. Sin características de bajo ruido o alta precisión en comparación con otros sensores.
ADXL345 | 7000-12000 COP | 2V-3.6V | 30uA – 150 uA (2.5V) | Bajo consumo de energía, ideal para aplicaciones alimentadas por batería. Amplio rango de ±2g, ±4g, ±8g, ±16g, configurable según la aplicación. Comunicación por I2C y SPI, facilitando la integración. | No es el más preciso en comparación con otros acelerómetros más avanzados. Tecnología más antigua, aunque sigue siendo ampliamente utilizada.

MPU6050 : https://www.alldatasheet.es/datasheet-pdf/download/517744/ETC1/MPU-6050.html

ADXL345: https://www.analog.com/media/en/technical-documentation/data-sheets/adxl345.pdf

LEDs

* Dependiendo del microcontrolador, la tarjeta puede tener LED, por lo que al elegir la tarjeta Nordic, no se incluye.

Componente | Precio | Voltaje | Corriente | Ventajas | Desventajas
Leds SMD 0805 | 300 COP | 2.7v-3.7v | 25 mA | Tamaño compacto, ideal para aplicaciones donde el espacio es limitado. Disponible en una variedad de colores. Bajo costo y ampliamente disponible. | Brillo limitado en comparación con LEDs más grandes. Requiere una cuidadosa soldadura debido a su pequeño tamaño.
Leds SMD 5050 | 400 COP | 2V-3.6V | 60-75 mA | Alto brillo, adecuado para iluminación y efectos visuales. Capaz de emitir varios colores (RGB) en un solo paquete. Relativamente fácil de soldar debido a su tamaño. | Consumo de energía más alto debido a los múltiples chips. Ocupa más espacio en la PCB.
Leds SMD 3528 | 300 COP | 1.7V-2.4V | 50 mA | Tamaño intermedio, adecuado para aplicaciones de señalización y decoración. Disponible en varios colores, incluyendo opciones de alto brillo. Más eficiente que los LEDs 5050 en términos de consumo de energía por chip | Menos brillante que los LEDs 5050. Menor gama de colores comparado con LEDs RGB.

Led SMD 0805: https://www.mouser.com/datasheet/2/143/17-21-BHC-AP1Q2-3T_datasheet-51933.pdf

Led SMD 5050: https://www.iled.com/class/INNOVAEditor/assets/YeniDatasheets/4050-4055-4057.pdf

Led SMD 3528: https://www.sigmaelectronica.net/wp-content/uploads/2018/08/LED-3528BLANCO.pdf

Alimentación

Componente | Precio | Voltaje | Corriente | Ventajas | Desventajas
Batería de litio-polímero | 25000-30000 COP | 3.7v | 500-1000 mAh | Alta densidad de energía, lo que permite una mayor capacidad en un tamaño pequeño. Forma flexible, disponible en diferentes formas y tamaños, ideal para aplicaciones compactas. Peso ligero, adecuado para dispositivos portátiles. | Requiere un manejo cuidadoso para evitar sobrecargas o sobre-descargas, que pueden causar daños. Vida útil limitada en comparación con otras baterías recargables. Puede ser más cara que otras opciones de baterías.

Batería Li-Po: https://www.zamux.co/bateria-recargable-litio-37v-500ma

Módulo de Carga

Componente | Precio | Voltaje | Corriente | Ventajas | Desventajas
TP4056 y puerto MiniUSB | 4000 COP | Input supply voltage: 4.25 – 6.5V | Input supply current: 35uA – 2 mA | Muy económico y ampliamente disponible. Configurable para diferentes corrientes de carga mediante la modificación de una resistencia. Fácil de integrar en proyectos DIY debido a su tamaño compacto. | Sin protección integrada por defecto (aunque hay versiones con protección). La corriente de carga puede ser limitada para baterías de mayor capacidad. Requiere soldadura si se necesita ajustar la corriente de carga.
Módulo de carga MCP73831 | 18000 COP | Input supply voltage: 3.75 – 6V | Input supply current: 510uA – 1.5 mA | Bajo consumo en reposo, ideal para aplicaciones de bajo consumo de energía. Muy eficiente en la gestión de la carga, prolongando la vida útil de la batería. Pequeño y fácil de integrar en PCB personalizadas. | Corriente de carga más baja (hasta 500 mA), lo que puede ser una limitación para baterías más grandes. Puede requerir componentes externos adicionales para ajustar el circuito.

TP4056: https://radioremont.com/wa-data/public/shop/products/32/33/3332/attachments/TP4056.pdf

MCP73831: https://www.alldatasheet.es/datasheet-pdf/download/305677/MICROCHIP/MCP73831.html

Circuito de Activación por Pulsador

Pulsador

Componente | Precio | Voltaje | Corriente | Ventajas | Desventajas
SW 4P NO | 400 COP | <42 V | <50mA | Tamaño pequeño, bajo costo. | Su tamaño puede dificultar la experiencia de usuario.

SW 4 Pines: https://cdn.soselectronic.com/productdata/f4/94/44a0b902/0862-8101.pdf

Mosfet Tipo N

Componente | Precio | Voltaje | Corriente | Ventajas | Desventajas
2N7002 | 600 COP | VGS (th): 1V to 2.5V | I DSS: 1 to 500 uA | Tamaño pequeño, bajo costo. | Difícil de soldar.

2N7002: https://www.diodes.com/assets/Datasheets/ds11303.pdf

Mosfet Tipo P

Componente | Precio | Voltaje | Corriente | Ventajas | Desventajas
FDN340P | 300 COP | VGS (th): -0.4V to -1.5V | I DSS: 1 to 10 uA | Tamaño pequeño, bajo costo. | Difícil de soldar

FDN340P: https://www.onsemi.com/pdf/datasheet/fdn340p-d.pdf

Resistencias:

Componente | Precio | Voltaje | Corriente | Ventajas | Desventajas
RES 1206 220 Ohm | 500 COP | Max 3.3V | Max 15mA
RES 1206 10k Ohm | 500 COP | Max 3.3V | Max 330uA
RES 1206 1M Ohm | 500 COP | Max 3.3V | Max 3,3uA

Diodos

Componente | Precio | Voltaje | Corriente | Ventajas | Desventajas
1N4004 SMD | 200 COP | 0.7V | Average Forward Rectifier Current: 100mA | Tamaño pequeño, bajo consumo de energía, bajo costo

1N4007: https://www.alldatasheet.es/datasheet-pdf/download/209682/FCI/1N4007.html

Sensor de Apertura: Detección de Billetera Abierta/Cerrada

Componente | Precio | Voltaje | Corriente | Ventajas | Desventajas
Reed Switch ORD213 | 1200 COP | < 24 V | <100mA | Tamaño pequeño, bajo costo. | Requiere un imán/campo magnético al otro extremo para su activación/desactivación.

ORD213: https://standexelectronics.com/wp-content/uploads/OKI_Reed_Switch_ORD213.pdf

Regulador de Voltaje 3.3V

ME6217-3.3V | $0.075 USD | 3.4-6.5V Dropout Voltage: 100mV | Max Current Output: 800mA | Baja Caída de Voltaje Amplio rango de voltaje de operación | Reducción en la corriente de salida Difícil de conseguir
MIC502-3.3V | 600 COP | 3.4-6.5V Dropout Voltage: 150mV | Max Current Output : 500 mA Quiescent Current: 5uA | Fácil de conseguir Baja caída de voltaje Rango de Voltaje de Operación Óptimo | Voltaje de caída más alto dependiendo de la corriente de entrada Corriente de salida más baja

ME6217C33: MICRONE(Nanjing Micro One Elec) ME6217C33M5G Datasheet (lcsc.com) (https://www.lcsc.com/datasheet/lcsc_datasheet_1912111437_MICRONE-Nanjing-Micro-One-Elec-ME6217C33M5G_C427602.pdf)

MIC5205-3.3: https://www.vistronica.com/index.php?controller=attachment&id_attachment=574

Capacitores y Condensadores

Condensador Cerámico e Inductancia SMD | | 600 COP | | | Bajo costo Tamaño Reducido | Entre menor tamaño, más difícil para soldar

Diodo Zener

Zener SMD 3.6V | 200 COP | 3.6V | 5mA | Bajo costo Tamaño Reducido | Difícil para soldar

Zener 3.6V: Diodo Zener BZT52C3V6S W4 3.6V 200mW SMD SOD-323 (vistronica.com) (https://www.vistronica.com/componentes-activos/diodos/diodo-zener-bzt52c3v6s-w4-3-6v-200mw-smd-sod-323-detail.html)

Bocina

Bocina piezoeléctrica SMD: CMT-2020 | $2 USD | 2.5V-4.5V | 120mA | Tamaño pequeño, consumo de voltaje apropiado, bajo costo | No tiene un volumen muy alto, el sonido puede no ser de tan alta calidad Consumo de corriente considerable Difícil de conseguir
Bocina Piezoeléctrica CST-951AP | 1250 COP | 3-12V | 30mA | Menor consumo de corriente Más fácil de conseguir | Tamaño más grande Volumen variable

CMT6504: CMT-6504-85-SMT-TR Datasheet - Audio Transducers | Buzzers | CUI Devices (mouser.com) (https://www.mouser.com/datasheet/2/670/cmt_6504_85_smt_tr-3388235.pdf)

CST-951AP: https://www.snapeda.com/parts/CST-951AP/CUI%20Devices/datasheet/

3.4.2 Diagrama de Bloques Nivel 2


Fase 4: Diseño de Esquemático


Fase 5: Diseño de PCB


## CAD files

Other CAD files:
casing_design/3d_models/Carcasa.f3d

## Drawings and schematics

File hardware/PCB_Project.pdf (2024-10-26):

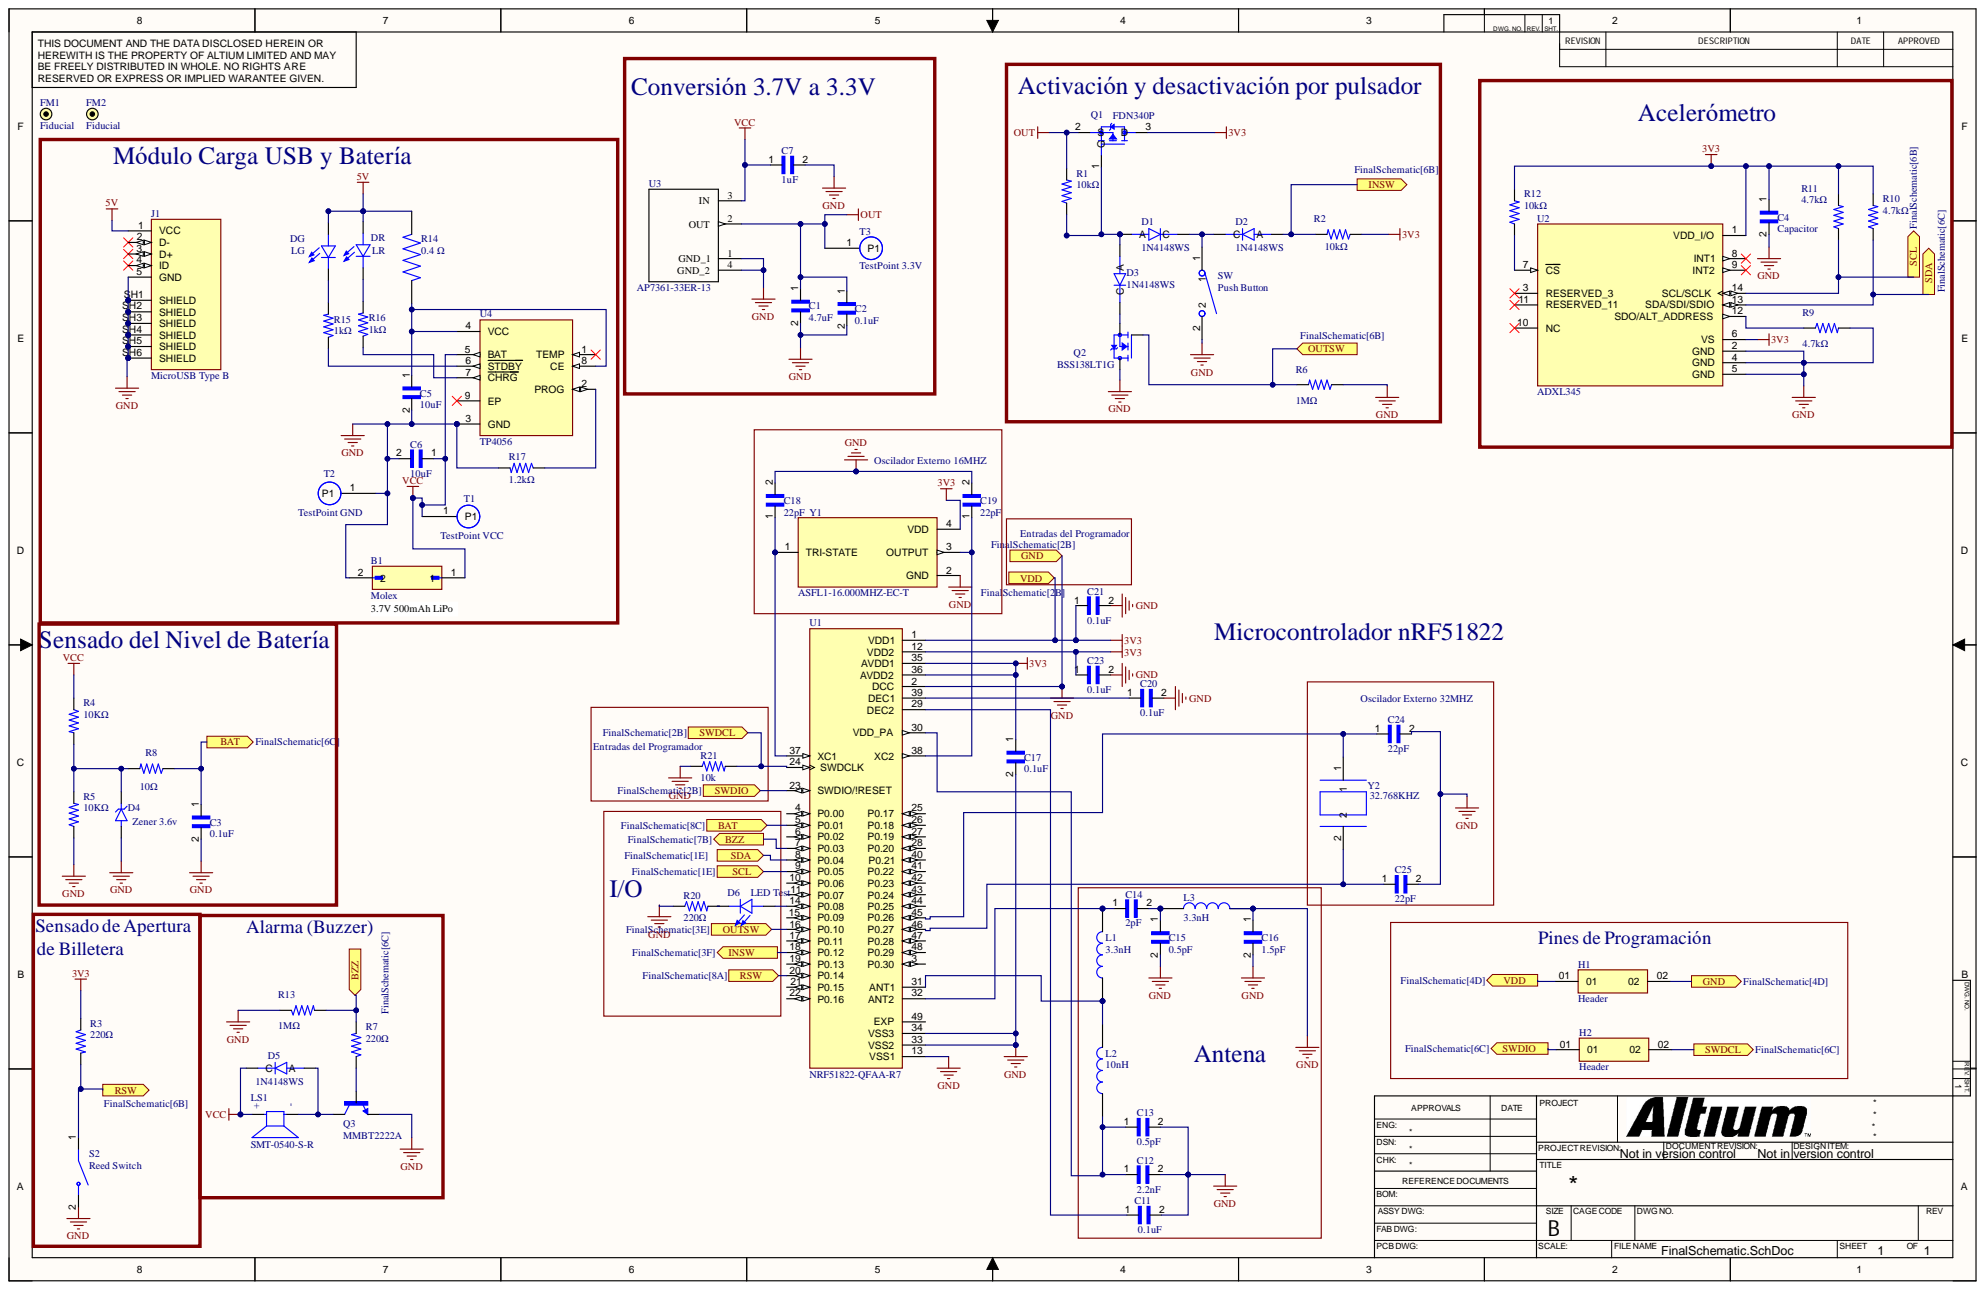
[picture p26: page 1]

DWG. NO. | REV. | 1 SHT.

THIS DOCUMENT AND THE DATA DISCLOSED HEREIN OR HEREWITH IS THE PROPERTY OF ALTIUM LIMITED AND MAY BE FREELY DISTRIBUTED IN WHOLE. NO RIGHTS ARE RESERVED OR EXPRESS OR IMPLIED WARANTEE GIVEN. | | REVISION | DESCRIPTION | DATE | APPROVED

Fiducial
Módulo Carga USB y Batería

10uF VCC

Sensado del Nivel de Batería

REV. SHT. DWG. NO.

DATE | PROJECT | * * APPROVALS * *

ENG: *

DSN: * | | PROJECTREVISION: | DOCUMENTREVISION: Not in version control | DESIGN ITEM: Not in version control

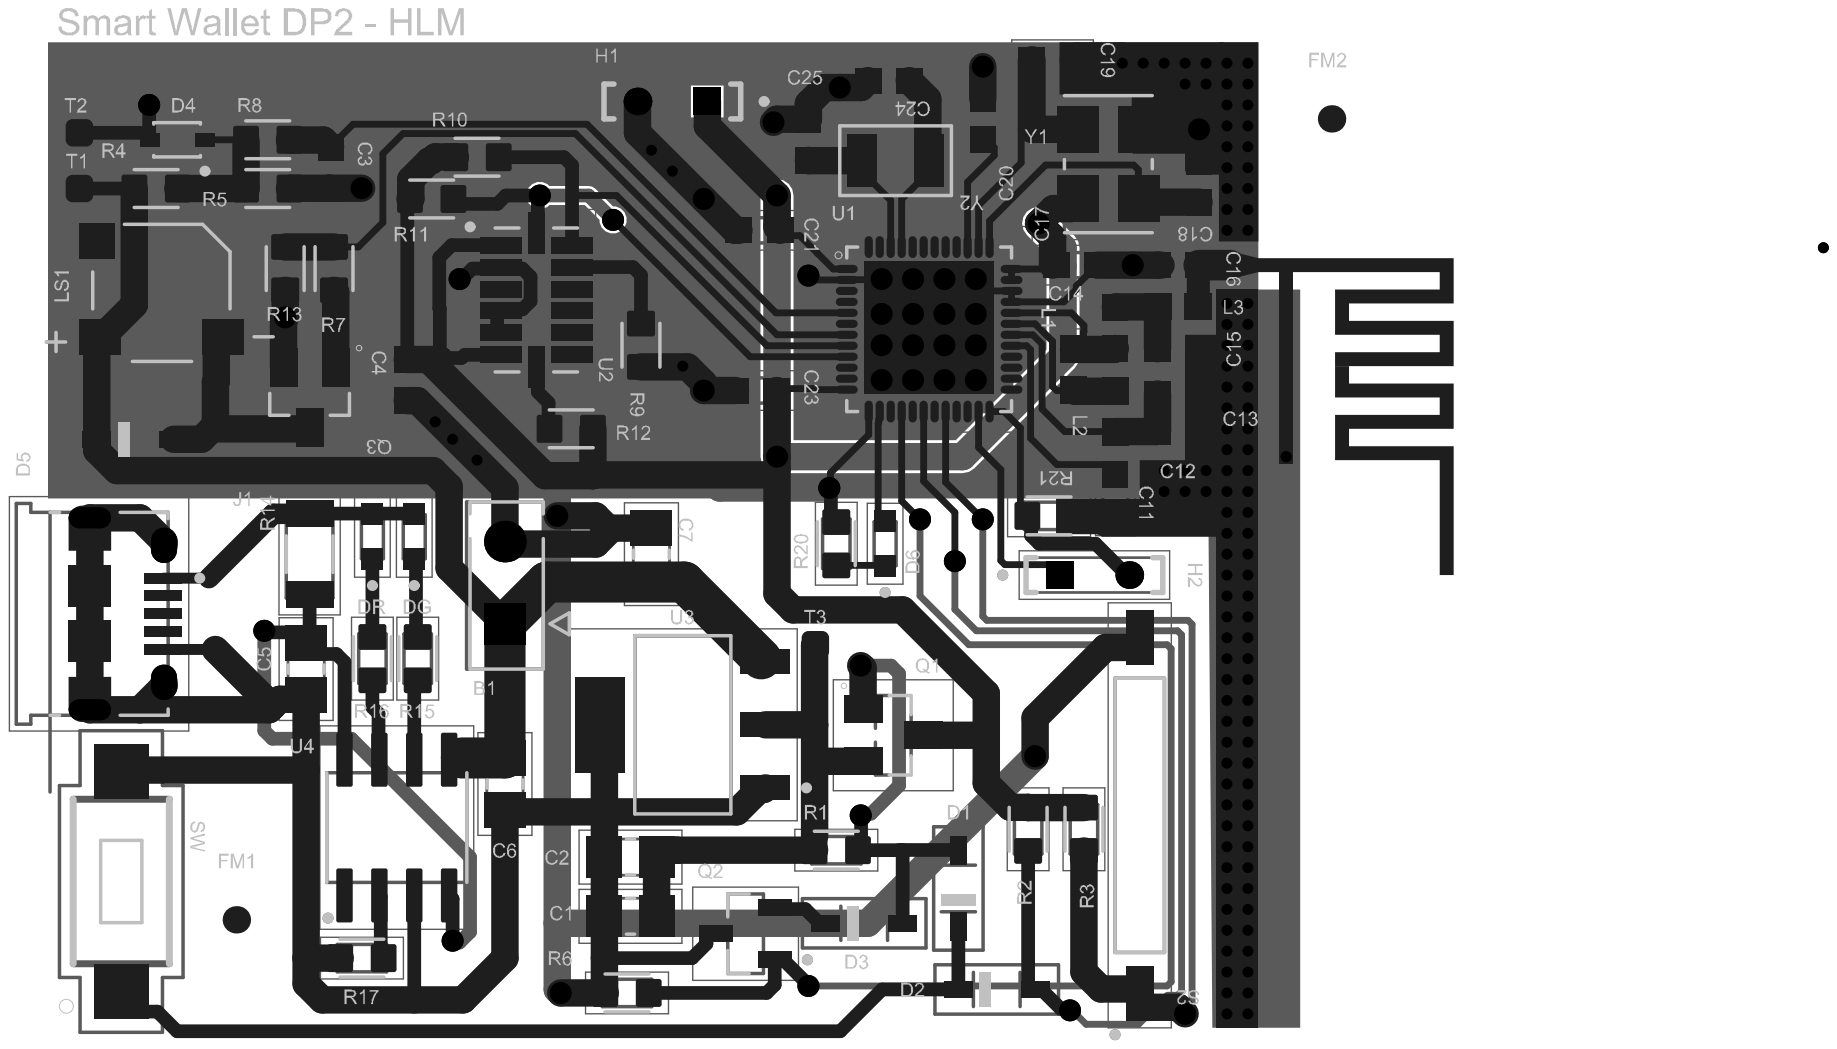
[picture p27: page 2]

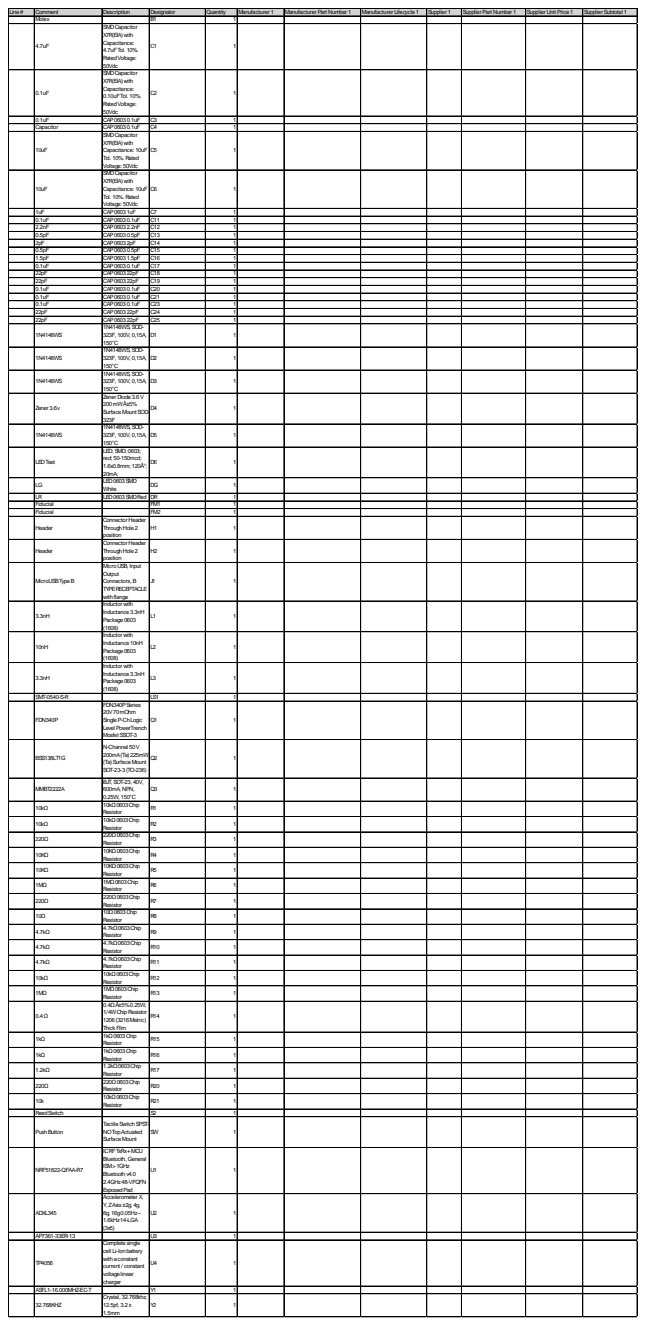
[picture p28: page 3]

4.7uF | SMDCapacitor X7R(EIA)with Capacitance: 4.7uFTol. 10%. RatedVoltage: 50Vdc | C1 | 1

0.1uF | SMDCapacitor X7R(EIA)with Capacitance: 0.10uFTol. 10%. RatedVoltage: 50Vdc | C2 | 1

0.1uF | CAP06030.1uF | C3 | 1
Capacitor | CAP06030.1uF | C4 | 1
10uF | SMDCapacitor X7R(EIA)with Capacitance: 10uF Tol. 10%. Rated Voltage: 50Vdc | C5 | 1

10uF | SMDCapacitor X7R(EIA)with Capacitance: 10uF Tol. 10%. Rated Voltage: 50Vdc | C6 | 1

1uF | CAP06031uF | C7 | 1
0.1uF | CAP06030.1uF | C11 | 1
2.2nF | CAP06032.2nF | C12 | 1
0.5pF | CAP06030.5pF | C13 | 1
2pF | CAP06032pF | C14 | 1
0.5pF | CAP06030.5pF | C15 | 1
1.5pF | CAP06031.5pF | C16 | 1
0.1uF | CAP06030.1uF | C17 | 1
22pF | CAP060322pF | C18 | 1
22pF | CAP060322pF | C19 | 1
0.1uF | CAP06030.1uF | C20 | 1
0.1uF | CAP06030.1uF | C21 | 1
0.1uF | CAP06030.1uF | C23 | 1
22pF | CAP060322pF | C24 | 1
22pF | CAP060322pF | C25 | 1
1N4148WS | 1N4148WS, SOD-323F, 100V, 0,15A, 150°C | D1 | 1

1N4148WS | 1N4148WS, SOD-323F, 100V, 0,15A, 150°C | D2 | 1

1N4148WS | 1N4148WS, SOD-323F, 100V, 0,15A, 150°C | D3 | 1

Zener 3.6v | Zener Diode3.6V 200mWÂ±5% SurfaceMount SOD-323F | D4 | 1

1N4148WS | 1N4148WS, SOD-323F, 100V, 0,15A, 150°C | D5 | 1

LEDTest | LED; SMD; 0603; red; 50-150mcd; 1.6x0.8mm; 120Â°; 20mA; | D6 | 1

LG | LED0603SMD White | DG | 1

LR | LED0603SMDRed | DR | 1
Fiducial | | FM1 | 1
Fiducial | | FM2 | 1
Header | Connector Header ThroughHole2 position | H1 | 1

Header | Connector Header ThroughHole2 position | H2 | 1

MicroUSBTypeB | MicroUSB, Input Output Connectors, B TYPERECEPTACLE with flange | J1 | 1

3.3nH | Inductor with Inductance3.3nH Package0603 (1608) | L1 | 1

10nH | Inductor with Inductance10nH Package0603 (1608) | L2 | 1

3.3nH | Inductor with Inductance3.3nH Package0603 (1608) | L3 | 1

SMT-0540-S-R | | LS1 | 1
FDN340P | FDN340PSeries 20V70mOhm SingleP-ChLogic Level PowerTrench Mosfet SSOT-3 | Q1 | 1

BSS138LT1G | N-Channel 50V 200mA(Ta)225mW (Ta)SurfaceMount SOT-23-3(TO-236) | Q2 | 1

MMBT2222A | BJT, SOT-23, 40V, 600mA, NPN, 0.25W, 150°C | Q3 | 1

10kΩ | 10kΩ0603Chip Resistor | R1 | 1

10kΩ | 10kΩ0603Chip Resistor | R2 | 1

220Ω | 220Ω0603Chip Resistor | R3 | 1

10KΩ | 10KΩ0603Chip Resistor | R4 | 1

10KΩ | 10KΩ0603Chip Resistor | R5 | 1

1MΩ | 1MΩ0603Chip Resistor | R6 | 1

220Ω | 220Ω0603Chip Resistor | R7 | 1

10Ω | 10Ω0603Chip Resistor | R8 | 1

4.7kΩ | 4.7kΩ0603Chip Resistor | R9 | 1

4.7kΩ | 4.7kΩ0603Chip Resistor | R10 | 1

4.7kΩ | 4.7kΩ0603Chip Resistor | R11 | 1

10kΩ | 10kΩ0603Chip Resistor | R12 | 1

1MΩ | 1MΩ0603Chip Resistor | R13 | 1

0.4Ω | 0.4ΩÂ±5%0.25W, 1/4WChipResistor 1206(3216Metric) ThickFilm | R14 | 1

1kΩ | 1kΩ0603Chip Resistor | R15 | 1

1kΩ | 1kΩ0603Chip Resistor | R16 | 1

1.2kΩ | 1.2kΩ0603Chip Resistor | R17 | 1

220Ω | 220Ω0603Chip Resistor | R20 | 1

10k | 10kΩ0603Chip Resistor | R21 | 1

ReedSwitch | | S2 | 1

PushButton | TactileSwitchSPST-NOTopActuated SurfaceMount | SW | 1

NRF51822-QFAA-R7 | ICRFTxRx+MCU Bluetooth, General ISM>1GHz Bluetoothv4.0 2.4GHz48-VFQFN ExposedPad | U1 | 1

ADXL345 | Accelerometer X, Y, ZAxis ±2g, 4g, 8g, 16g0.05Hz~ 1.6kHz14-LGA (3x5) | U2 | 1

AP7361-33ER-13 | | U3 | 1
TP4056 | Completesingle cell Li-Ionbattery with aconstant current / constant voltagelinear charger | U4 | 1

ASFL1-16.000MHZ-EC-T | | Y1 | 1
32.768KHZ | Crystal, 32.768khz, 12.5pf, 3.2x 1.5mm | Y2 | 1

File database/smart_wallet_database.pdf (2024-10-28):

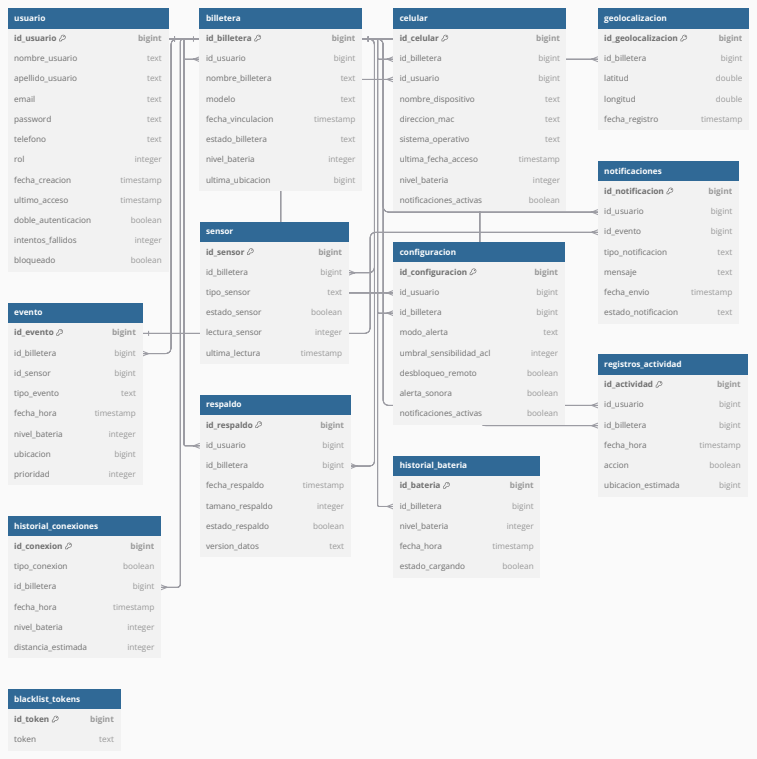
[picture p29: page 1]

id_sensor bigint | desbloqueo_remoto boolean
tipo_evento text | alerta_sonora boolean

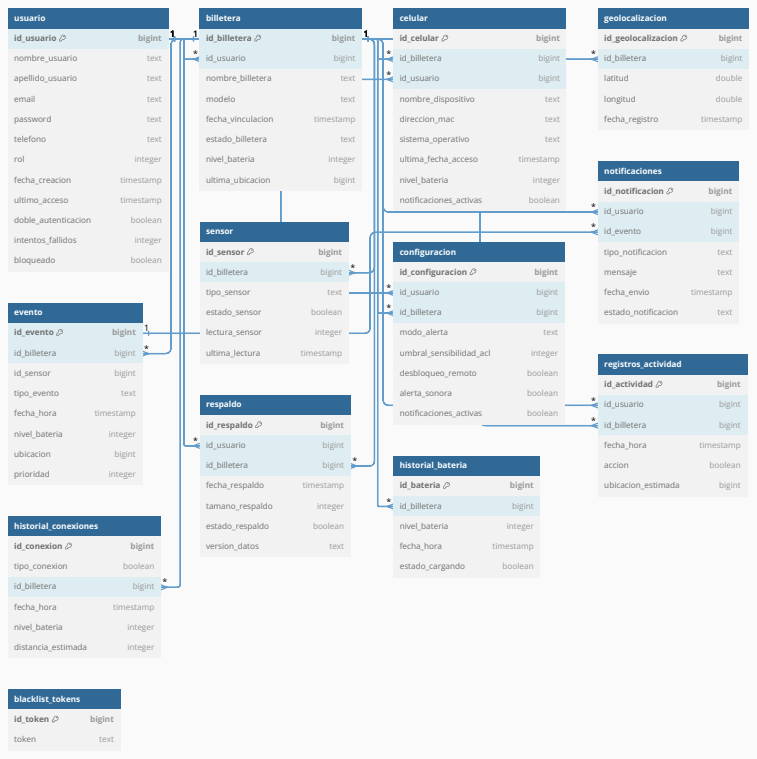
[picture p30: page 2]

id_sensor bigint | desbloqueo_remoto boolean
tipo_evento text | alerta_sonora boolean

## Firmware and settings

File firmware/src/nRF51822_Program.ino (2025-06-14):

#include <SPI.h>
#include <BLEPeripheral.h>
#include <Adafruit_Sensor.h>
#include <Adafruit_ADXL345_U.h>
#include <Wire.h>
#include <math.h>

// Definir pines para BLEPeripheral
#define BLE_REQ 9
#define BLE_RDY 6
#define BLE_RST 7

// Pines del sistema
#define REED_PIN 14
#define BUZZER_PIN 2
#define BATTERY_PIN 1
#define LED 8

// Crear instancia de BLEPeripheral
BLEPeripheral blePeripheral(BLE_REQ, BLE_RDY, BLE_RST);

// Crear servicio y características BLE
BLEService accelService("fff0");
BLECharacteristic accelMagnitudeCharacteristic("fff1", BLENotify, 20); // Característica para la magnitud
BLECharacteristic alertCharacteristic("fff2", BLENotify, 20);         // Característica para alertas
BLECharacteristic batteryCharacteristic("fff3", BLENotify, 20);       // Característica para nivel de batería
BLECharacteristic walletStateCharacteristic("fff4", BLENotify, 1);    // Característica para estado de billetera
BLECharacteristic buzzerStateCharacteristic("fff5", BLENotify, 1);    // Nueva característica para controlar el buzzer
BLECharacteristic buzzerControlCharacteristic("fff6", BLEWrite, 1);    // Nueva característica para controlar el buzzer

// Instancia del ADXL345
Adafruit_ADXL345_Unified adxl = Adafruit_ADXL345_Unified(12345);

// Umbrales para eventos
#define FALL_THRESHOLD 3       // Umbral ajustado para detectar caída libre
#define IMPACT_THRESHOLD 20    // Umbral para detectar movimiento brusco
#define BATTERY_LOW_PERCENTAGE 20 // Nivel de batería baja en porcentaje

bool isFalling = false; // Estado de caída libre
unsigned long lastUpdate = 0;       // Tiempo de la última transmisión
unsigned long lastAlertTime = 0;    // Tiempo del último mensaje de alerta
unsigned long lastBlinkTime = 0;    // Tiempo del último parpadeo del LED
bool ledState = false;              // Estado actual del LED
bool buzzerState = false;

// Definir pines para el control de encendido y apagado por pulsador
const int pinPulsador = 12;    // Pin donde está conectado el pulsador 
const int pinSalida = 10;      // Pin GPIO que mantiene encendida la ESP32 

bool estadoSalida = true;     // Estado inicial de la salida (encendida)
bool ultimoEstadoPulsador = LOW; // Último estado del pulsador

void setup() {
  // Configurar pines
  pinMode(REED_PIN, INPUT_PULLUP);
  pinMode(BUZZER_PIN, OUTPUT);
  pinMode(LED, OUTPUT);
  pinMode(pinPulsador, INPUT_PULLUP);
  pinMode(pinSalida, OUTPUT);

  // Inicializar I2C
  Wire.begin();
  // Configurar BLEPeripheral
  blePeripheral.setLocalName("MPU6050_BLE");
  blePeripheral.setAdvertisedServiceUuid(accelService.uuid());

  blePeripheral.addAttribute(accelService);
  blePeripheral.addAttribute(accelMagnitudeCharacteristic);
  blePeripheral.addAttribute(alertCharacteristic);
  blePeripheral.addAttribute(batteryCharacteristic);
  blePeripheral.addAttribute(walletStateCharacteristic);
  blePeripheral.addAttribute(buzzerStateCharacteristic);
  blePeripheral.addAttribute(buzzerControlCharacteristic);

  blePeripheral.begin();
  

  
}

// Función para medir el voltaje de la batería
float readBatteryVoltage() {
  int adcValue = analogRead(BATTERY_PIN); // Leer el valor analógico
  float voltage = (adcValue / 1023.0) * 3.6; // Convertir a voltaje (3.6V rango máximo con divisor)
  return voltage;
}

// Función para calcular el porcentaje de batería
int calculateBatteryPercentage(float voltage) {
  const float MAX_VOLTAGE = 3.3;
  const float MIN_VOLTAGE = 2.7;

  // Limitar el voltaje dentro del rango esperado
  if (voltage > MAX_VOLTAGE) voltage = MAX_VOLTAGE;
  if (voltage < MIN_VOLTAGE) voltage = MIN_VOLTAGE;

  // Calcular porcentaje (interpolación lineal)
  int percentage = ((voltage - MIN_VOLTAGE) / (MAX_VOLTAGE - MIN_VOLTAGE)) * 100;
  return percentage;
}

// Función para manejar la batería
void handleBattery() {
  float voltage = readBatteryVoltage();
  int batteryPercentage = calculateBatteryPercentage(voltage);

  String batteryMessage = String(batteryPercentage) + "%";
  batteryCharacteristic.setValue(batteryMessage.c_str());

  // Verificar si la batería está baja
  if (batteryPercentage <= BATTERY_LOW_PERCENTAGE) {
    alertCharacteristic.setValue("BL!"); // Enviar alerta BLE
  } 
}



// Función para manejar el estado del LED de conexión BLE
void handleBLEConnectionLED(bool isConnected) {
  if (isConnected) {
    digitalWrite(LED, LOW); // Apagar LED si está conectado
  } else {
    // Parpadeo del LED si no está conectado
    if (millis() - lastBlinkTime > 500) {
      lastBlinkTime = millis();
      ledState = !ledState;
      digitalWrite(LED, ledState);
    }
  }
}

void handleBuzzerControl() {
  if (buzzerControlCharacteristic.written()) {
    byte buzzerState = buzzerControlCharacteristic.value()[0]; // Acceder al primer valor
    if (buzzerState == 1) {
      analogWrite(BUZZER_PIN, 128); // Encender el buzzer con PWM
      buzzerState = true;

      
    } else {
      analogWrite(BUZZER_PIN, 0);   // Apagar el buzzer
      buzzerState = false;
      
    }
  }
}

void loop() {
  // Escuchar conexiones BLE
  BLECentral central = blePeripheral.central();

  bool isConnected = central.connected();

  // Manejar el LED de conexión BLE
  handleBLEConnectionLED(isConnected);

  if (isConnected) {
    if (!adxl.begin()) {
        alertCharacteristic.setValue("NAC"); // Enviar alerta BLE
      }
    if (central.connected() && adxl.begin()) {
      // Inicializar MPU6050
      
      adxl.setRange(ADXL345_RANGE_2_G);
      // Leer datos del MPU6050 y enviar por BLE cada 500 ms
      if (millis() - lastUpdate > 500) {
        lastUpdate = millis();

        sensors_event_t accel;
        adxl.getEvent(&accel);
        

        // Obtener los valores de aceleración
        float ax = accel.acceleration.x;
        float ay = accel.acceleration.y;
        float az = accel.acceleration.z;

        // Calcular la magnitud de la aceleración
        float accelMagnitude = sqrt(ax * ax + ay * ay + az * az);
        
        // Convertir la magnitud a cadena
        String accelMagnitudeString = String(accelMagnitude, 1) + "m/s^2"; // Con dos decimales

            
        // Crear una cadena con los valores de aceleración en los tres ejes
        String accelDataString = "X: " + String(ax, 1) + " Y: " + String(ay, 1) + " Z: " + String(az, 1); // Con dos decimales
        
        // Establecer el valor en la característica BLE
        accelMagnitudeCharacteristic.setValue(accelMagnitudeString.c_str());

        

        // Detectar caída libre
        if (accelMagnitude < FALL_THRESHOLD) {
          if (!isFalling) {
            isFalling = true;
            alertCharacteristic.setValue("FD!"); // Enviar alerta por BLE
            lastAlertTime = millis(); // Actualizar tiempo de última alerta
          }
        } else if (isFalling) {
          isFalling = false;
        }

        // Detectar movimiento brusco solo si no hay caída libre
        if (!isFalling && accelMagnitude > IMPACT_THRESHOLD) {
          alertCharacteristic.setValue("ID!"); // Enviar alerta por BLE
          lastAlertTime = millis(); // Actualizar tiempo de última alerta
        }

        // Verificar el estado del reed switch (estado de la billetera)
        bool isClosed = (digitalRead(REED_PIN) == LOW);
        walletStateCharacteristic.setValue(isClosed ? "1" : "0"); // Enviar estado como 1 o 0

        buzzerStateCharacteristic.setValue(buzzerState ? "1" : "0"); // Enviar alerta BLE
      }

      // Manejar el estado de la batería
      handleBattery();

      // Manejar el control del buzzer a través de BLE
      handleBuzzerControl();
    }
  }
  handlePulsador();
}

void handlePulsador() {
  bool estadoPulsador = digitalRead(pinPulsador);

  if (estadoPulsador == LOW && ultimoEstadoPulsador == HIGH) {
    // Cambiar estado del pin de salida
    estadoSalida = !estadoSalida;
    digitalWrite(pinSalida, estadoSalida ? HIGH : LOW);
    delay(200); // Retardo para evitar rebotes del pulsador
  }
  ultimoEstadoPulsador = estadoPulsador;
}

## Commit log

2024-09-18 Create PCB-V2
2024-09-18 Update PCB-V2
2024-09-24 Update and rename PCB-V2 to PCB-V3
2024-10-26 Update and rename PCB-V3 to docs/PCB-Final-V-Download
2024-10-26 Update PCB-Final-V-Download
2024-12-12 Rename Carcasa v3.f3d to Carcasa.f3d
    [Carcasa.f3d]
2025-06-14 Refactor
    Organizing
    [Carcasa.f3d]
2025-06-14 PCB FIles
    Added
    [FinalSchematic.SchDoc, PCB1-V2.PcbDoc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]
